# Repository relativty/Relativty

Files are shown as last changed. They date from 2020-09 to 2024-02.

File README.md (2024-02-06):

<h1 align="center">
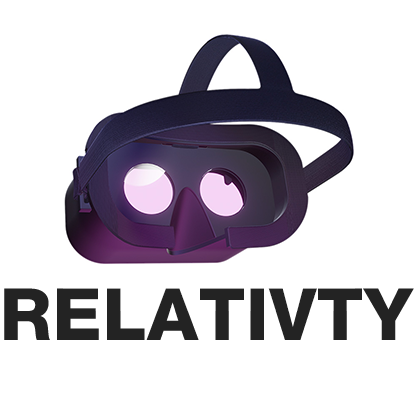
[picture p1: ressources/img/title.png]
Relativty
	
</h1>

<h3 align="center">
	Open-source VR headset with SteamVR support.
</h3>
<p align="center">
	<strong>
		<a href="https://relativty.com">Website</a>
		•
		<a href="https://discord.gg/jARCsVb">Discord</a>
	</strong>
</p>

I’m <a href="https://twitter.com/maxim_xyz?lang=en">Maxim xyz</a> and when my best friend Gabriel Combe and I were 15 years old we built our own VR headset because we couldn't afford to buy one.

5 years later : this headset became Relativty.

* Fully Open-source - **hardware**, **software**, **firmware**.
* **Steam VR** support.
* Natively displays **2K** resolution at **120FPS**.
* Compatible with **Arduino**.
* Experimental **Body-Tracking**

**This repo serves as a Build guide, to learn more about the headset see you at <a href="https://relativty.com">Relativty.com</a>**

Made for Hackers
-
Relativty is **NOT A CONSUMER PRODUCT**. We made Relativty in my bedroom with a soldering iron and a 3D printer and we expect you to do the same: **build it yourself**.

Relativty at its basics is a 3 Degrees of Freedom (3-DoF) VR headset with no built-in controller support, designed to work with SteamVR.
This may limit its practical usability for games that demand knuckle-style VR controllers.
If you are looking for a more full-featured DIY VR project 6-Dof tracking and controller support, we recommend you check out <a href="https://github.com/HadesVR/HadesVR">HadesVR</a>.

Whether or not you are building either Relativty or HadesVR, or if you just want to join our community and hang out, we invite you to <a href="https://discord.gg/F8GNKjy6RF">Relativty's Guild on Discord</a>.

It is a place for the DIY/Open-Source VR community to learn, grow, share knowledge, and ask for help. 

# Start Building Relativty

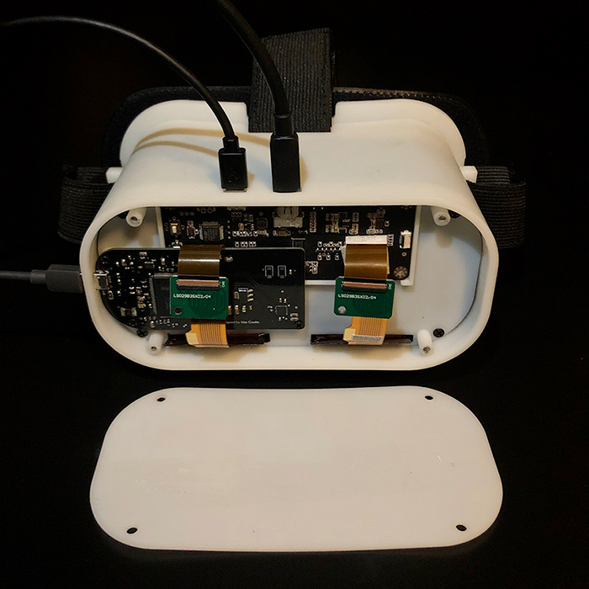
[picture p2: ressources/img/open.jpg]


# Building The Hardware
## 1. CURRENT RECOMMENDED BUILD - As of May 2023
### 1.1 Introduction
This is an updated build guide to help people who recently discovered Relativty. It aims to explain how to build the minimum functional product, which can be further improved upon and modified to the individual's liking. The original build guide can still be found further below.

            Following this guide to build a Relativty headset assumes basic understanding of electronics and programming Arduino boards.
            A VR headset is a complex system and can be difficult to figure out what is not working if you get stuck with the build.
            If you encounter any issues, join our Discord and ask for help, we are happy to assist.

### 1.2 ELECTRONICS

The following electronic components are required:

- ATmega32U4 Microcontroller (MCU) with USB HID support, such as an <a href="https://www.amazon.co.uk/diymore-Atmega32U4-Development-Microcontroller-Header/dp/B0BKGSVX2X">Arduino Pro Micro</a>
- Inertial Measurement Unit (IMU) that is supported by the <a href="https://github.com/LiquidCGS/FastIMU">FastIMU Library</a>
- A small, high resolution and high refresh rate PC display + driver board. <a href="https://github.com/HadesVR/HadesVR/blob/main/docs/Headset.md#displays">This segment of the HadesVR documentation presents possible good options you can choose from</a>. It is important to note that these displays connect to a DRIVER BOARD, which then connects to your computer. ALWAYS purchase the driver board and display(s) in the same bundle if you can to ensure they are compatible with each other. If you have further questions about displays, join us at <a href="https://discord.gg/F8GNKjy6RF">Relativty's Guild on Discord</a>.
```
NOTES on VR DISPLAYS:
- The display does not connect to the Microcontroller, it only connects to the Computer running your VR Apps.
- Technically, any PC display/monitor can be configured as the display used by Relativty. Therefore, you can simply test your build on your PC monitor
first to make sure it works, before you decide to spend a significant amount of money on lenses, display(s) and other parts.
- High performance, small form factor displays are expensive, and often very delicate. Handle them with care! :)
```

### 1.2.1 Wiring the IMU and MCU
The IMU needs to be connected to the MCU for power and communication.
The MCU connects to your computer via USB to send the IMU readings to SteamVR.

In case of an Arduino Pro Micro, you need to connect the following pins:
```
Pro Micro       IMU
VCC         ->  VCC  
GND         ->  GND  
SDA(pin 2)  ->  SDA  
SCL(pin 3)  ->  SCL  
```  
If you use a different MCU, the SDA and SCL pins might be mapped to different pin numbers.

Also, make sure that the VCC of your MCU is compatible with the rated operating voltage of your IMU.

Supplying incorrect voltage to electronic components may cause damage to them.

The MCU itself simply connects to your computer via the USB port.

### 1.2.2 Connecting the display
As mentioned previously, any display that is compatible with a personal computer should be able to function as your VR display.

In case you are using the recommended one or a similar component that is powered via micro-USB or other USB standard, it is possible that you will encounter situations where the board does not power up. This could be either because the micro-USB cable you are using is too long (so the board cannot power up because the voltage dropped too much), or the board is unable to turn on because the USB port it connects to on the computer side is simply unable to supply enough power. In this case, you might need to try different ports on your computer or a powered USB hub.

### 1.3 MECHANICAL BUILD

The following parts are required for the Mechanical Build:

- Housing - .STL files for 3D-printable model provided in Relativty_Mechanical_build folder.
- Lenses -  for building the 3D-printable headset, Lenses with 40mm diameter/50mm focal length required. You can often find these on Aliexpress or similar.
- Strap and Facial Interface - e.g. replacement strap + foam for HTC Vive. You can often find these on Aliexpress or similar.

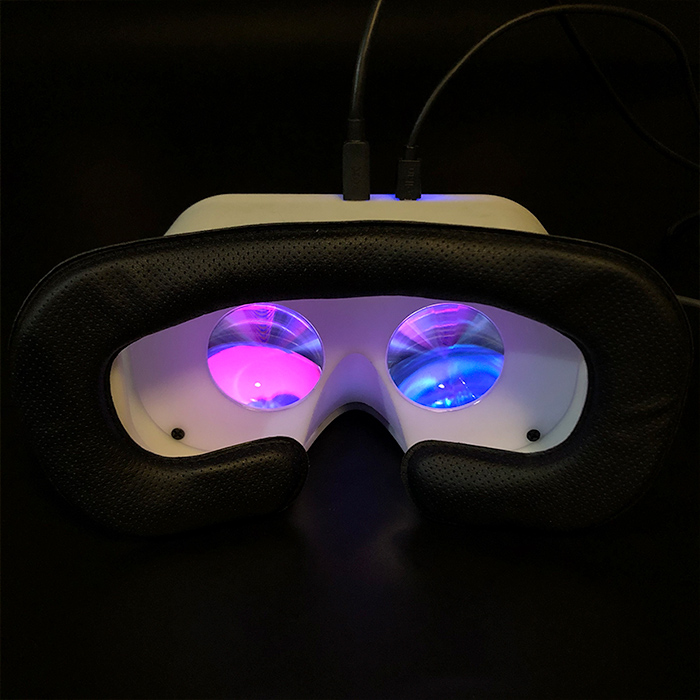
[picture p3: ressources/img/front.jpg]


If you do not have access to 3D-printing, it is also possible (and MUCH simpler) to just use an Android VR Phone case, and modify it to fit your screen and so that you can attach your IMU and MCU to it.

The advantage of this approach is that you get everything in one package, often including IPD adjustment.

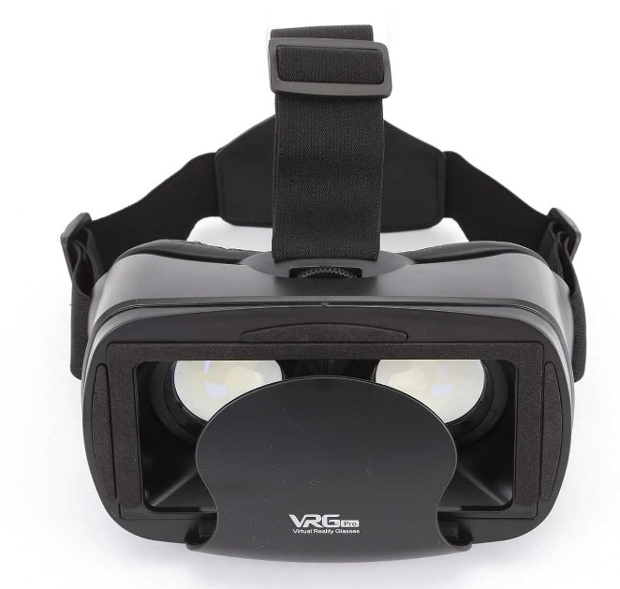
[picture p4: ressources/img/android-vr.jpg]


### 1.4 SOFTWARE SETUP

### 1.4.1 Introduction

Relativty depends on 2 main software components:
- the Arduino firmware
- the SteamVR driver

As the system is designed to work with SteamVR, you need to have Steam installed and SteamVR downloaded on your computer.

### 1.4.2 Programming your MCU

As previously mentioned, we recommend you use an Arduino Pro Micro and an IMU supported by the FastIMU Library.
FastIMU is an awesome package that supports many commonly used IMUs and comes with a pre-written Arduino sketch that works with Relativty.

First, you will need to install the Arduino IDE and connect your MCU to your computer via the USB connector.

Once you have it connected and verified your Arduino IDE can work with your MCU, download FastIMU from the library manager.

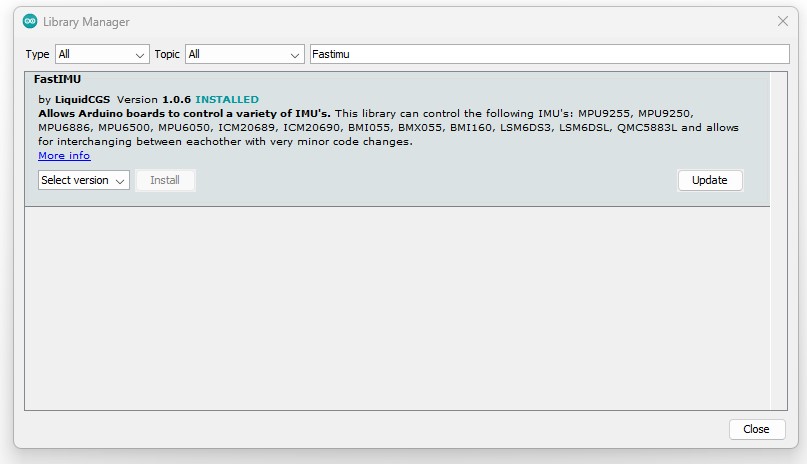
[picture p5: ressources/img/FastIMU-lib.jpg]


Wire up your IMU as recommended in Section 1.2.1.

Find the Examples/Fastimu/Calibrated_relativty sketch in your Arduino IDE:
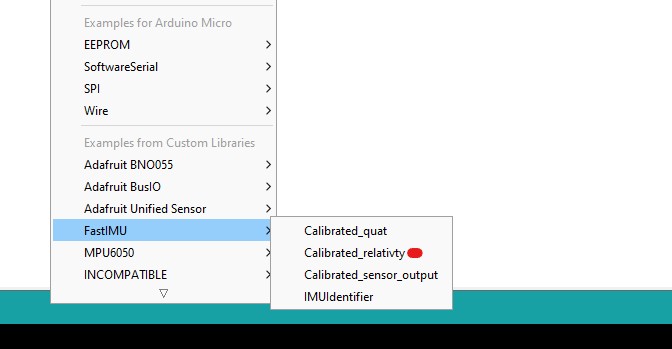
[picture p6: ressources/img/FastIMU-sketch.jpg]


And finally, Upload it to your MCU.

FastIMU also includes a built-in calibration tool that can store the calibration data on the IMUs EEPROM.

Calibrating the IMU may help with sensor drift that you can experience over time while using Relativty.

After uploading Calibrated_relativty sketch to the IMU, you can open the Arduino Serial Monitor to initiate a calibration sequence:

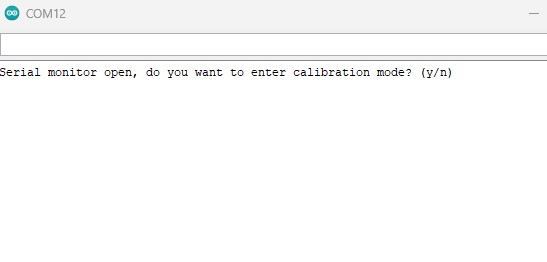
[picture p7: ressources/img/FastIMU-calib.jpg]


      NOTE: you only have to do this once, but make sure to follow the instructions given to you in the serial monitor.

### 1.4.3 Installing The SteamVR Driver

To install the Relativty SteamVR driver:
- download the <a href="https://github.com/relativty/Relativty/archive/refs/heads/master.zip">master repository</a>
- inside Relativty-master find the Relativty_Driver\Relativty folder and copy it to your SteamVR installation's drivers directory.
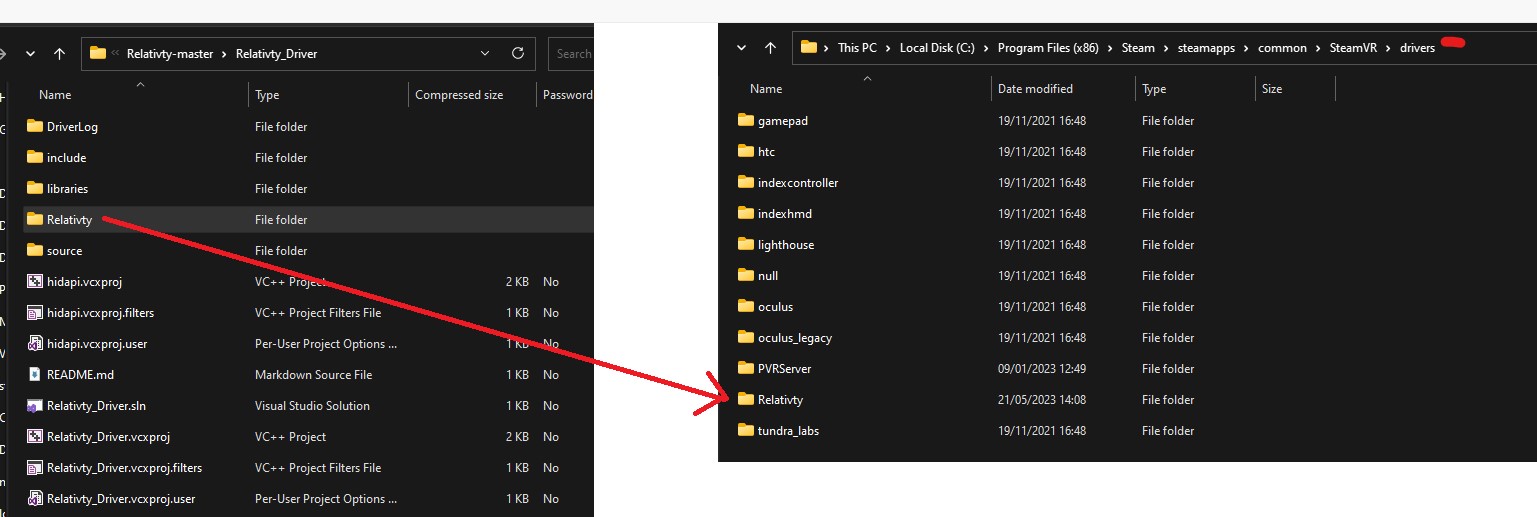
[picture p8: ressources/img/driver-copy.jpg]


### 1.4.4 Configuring The SteamVR Driver

Once you copied the driver files, it is time to configure the driver to work with your setup and computer.

Inside drivers\Relativty\resources\settings, there should be a file called default.vrsettings.

This is the configuration file for the driver.

There are a few things that you need to change.

### Configuring the driver to talk to the MCU
ASSUMING you use an Arduino Pro Micro and the FastIMU library:

In the Relativty_hmd segment find these values:
- hmdPid
- hmdVid
- hmdIMUdmpPackets

and change the values like so:

```
      "hmdPid" : 32823,
      "hmdVid": 9025,
      "hmdIMUdmpPackets":  false,
```

If you are using a different MCU, you need to figure out the USB PID and VID values.

Easiest way is to connect it to your computer via USB and check in Arduino IDE.

In the menu bar, select Tools/Get Board Info:
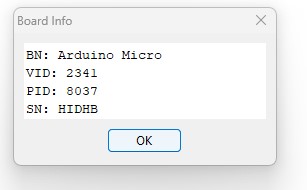
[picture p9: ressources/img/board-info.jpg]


Take the PID and VID values and convert them to decimal with a <a href="https://www.rapidtables.com/convert/number/hex-to-decimal.html">hex converter</a>.

The converted values then go into the hmdPid and hmdVid values in default.vrsettings.

### Configuring the Display Settings
Now let's look at configuring the driver to work with your Display.

The config variables for the display are in the Relativty_extendedDisplay segment:

For the VR Viewport window's point of origin:
```
      "windowX" : 3440,
      "windowY" : 0,
```

For the VR Viewport's actual size
```
      "windowWidth" : 1920,
      "windowHeight" : 1080,
```

For the VR Viewport's rendering resolution - this should be normally the same as the size
```
      "renderWidth" : 1920,
      "renderHeight" : 1080,
```

And some miscellaneous settings:
```
      "DistortionK1" : 0.4,
      "DistortionK2" : 0.5,
      "ZoomWidth" : 1,
      "ZoomHeight" : 1,
      "EyeGapOffsetPx" : 0,
      "IsDisplayRealDisplay" : true,
      "IsDisplayOnDesktop" : true
```
If the point of origin and size is not configured correctly, the driver will crash and SteamVR will not display anything!

Therefore we need to have a look at and understand the coordinate system SteamVR uses for displays.

Windows always assumes one of the connected displays as your Primary Display.

You can verify which one is your Primary in Display Settings.

You can select each of your displays with the mouse. The one that has "Make this my main display" checkbox greyed out is your Primary Display.

THIS GUIDE ASSUMES THAT THE TOP EDGE OF ALL OF YOUR DISPLAYS ARE ALIGNED IN WINDOWS DISPLAY SETTINGS (as seen on the screenshots)

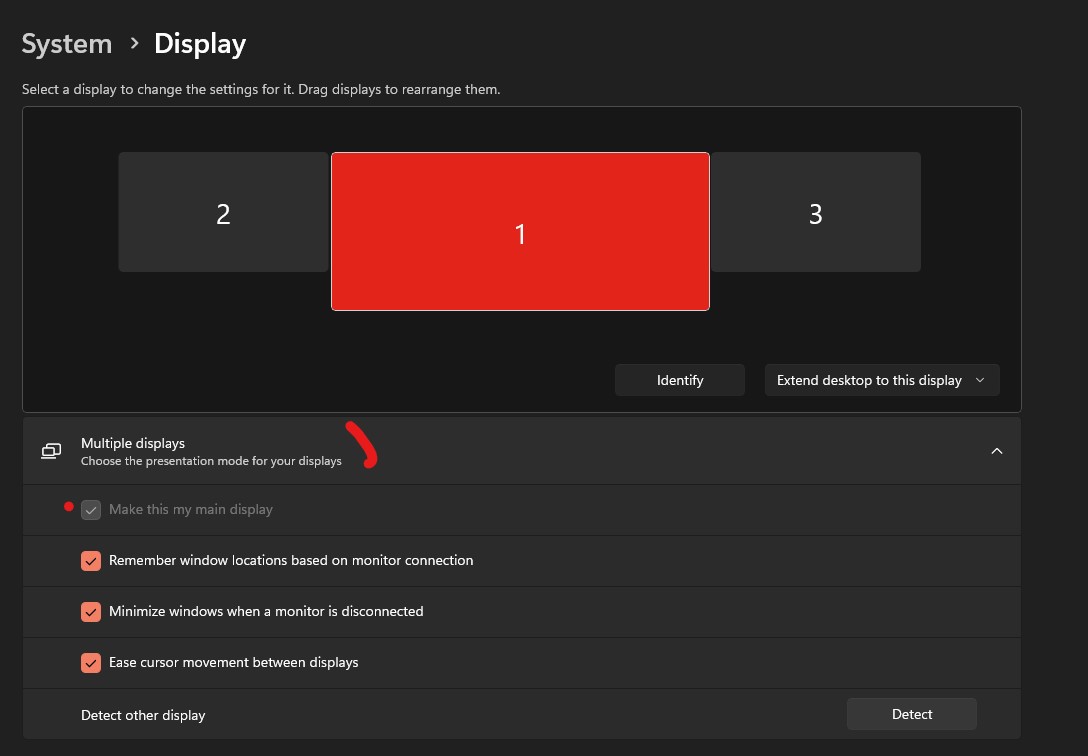
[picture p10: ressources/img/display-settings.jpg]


Consequently, checking the same on another, non-primary display will make that one your Primary.

The TOP LEFT corner of your Primary Display is the ORIGIN POINT of SteamVR's display coordinate system.

To be able to tell SteamVR where to draw the VR Viewport on your displays, you need to make sure you understand this fact and as a result can identify the correct point of origin for the Viewport.

For example, in a setup like this:

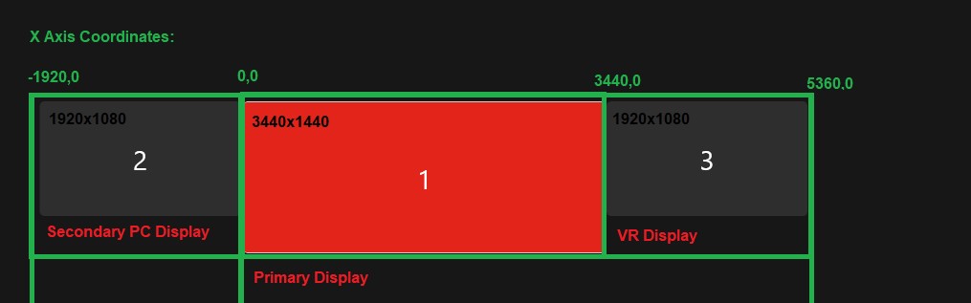
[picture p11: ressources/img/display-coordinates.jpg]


Because the "1" screen is the primary, and the "3" screen is the VR Display, the origin point (the 0,0 coordinate) is on the top left of the "1" screen.

This screen has 3440x1440 resolution.

This means it occupies the X axis from 0 to 3439, and the next screen on its right starts at point 3440.

Therefore, in this case the correct windowX and windowY values are:

```
      "windowX" : 3440,
      "windowY" : 0,
```

If "2" screen was the VR display (and "1" is still the Primary), the correct values would be:

```
      "windowX" : -1920,
      "windowY" : 0,
```
Because the "2" screen's coordinates occupy space over the other side of the origin point.

For windowWidth,windowHeight,renderWidth,renderHeight, simply set the Native Resolution of your VR display.

Once this is all set, save the settings file.

Now you should be ready to start SteamVR.

If everything is set up right, you should get straight into the vr holodeck area:

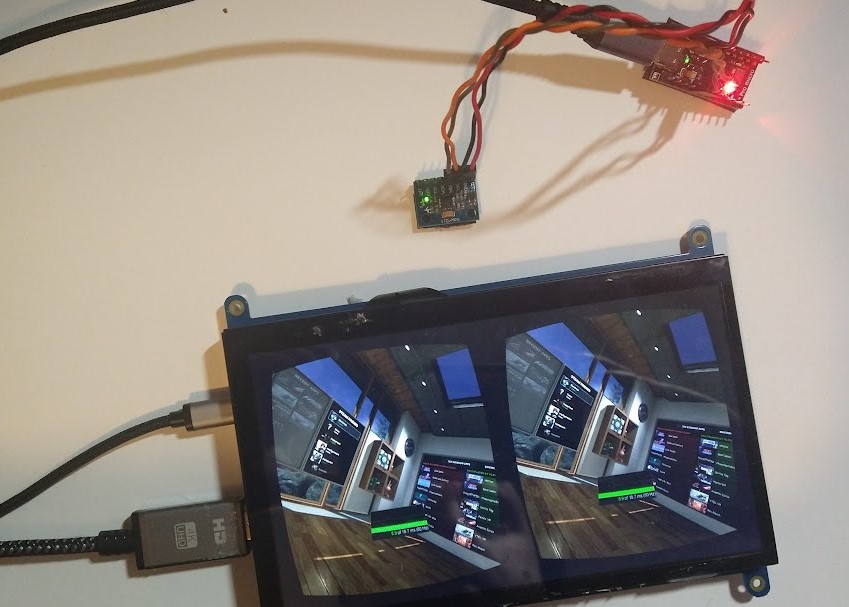
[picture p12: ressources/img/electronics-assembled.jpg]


If you are encountering any issues with your build:
- open the SteamVR Web Console and copy the entire log file
- Join <a href="https://discord.gg/F8GNKjy6RF">Relativty's Guild on Discord</a>, tell us about the issues you are facing, and upload the log file in the chat. 
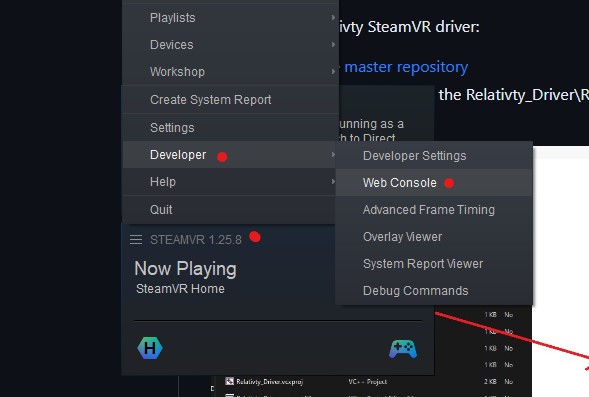
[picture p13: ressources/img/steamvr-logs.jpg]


### IF YOUR VR WINDOW DISAPPEARS AFTER CLICKING ON IT:

Open Windows PowerShell and paste these commands into the command line, then hit enter:

```
get-process vrcompositor | stop-process -Force;cd "C:\Program Files (x86)\Steam\steamapps\common\SteamVR\bin\win64";.\vrcompositor.exe
```

Afterwards the VRCompositor should remain stable, so you only have to do this once per session.

# 2. LEGACY BUILD
The hardware is based on the Relativty Motherboard which includes an Atmel SAM3X8E ARM Cortex-M3 processor and uses an MPU-6050 as it’s IMU.
Alternatively, any processor that supports the ArduinoCore and is connected to an MPU-6050/MPU-9250 can be used as the hardware for Relativty. Both methods are explained below.

## Building The Relativty Motherboard
### PCB Manufacturing.

We first start with the naked PCB.

it can be manufactured and bought for around $4 on websites like <a href="https://jlcpcb.com/">jlcpcb</a>.

You’ll need to provide the Gerber file folder `Relativty_Electronics_build/GerberFiles.zip` which describes the shape of the board.

### Assembling

Soldering the components onto the naked PCB. 

You’ll have to buy the components listed in one of the two BOMs, depending on availability:
- `Relativty_Electronics_build/Assembly/jlcpcb.com_motherboard_BOM.csv` 
- `Relativty_Electronics_build/Assembly/motherboard_BOM.xlsx`

Where to position those components on the PCB is described in the file `Relativty_Electronics_source/motherboard.brd` which can be opened in Eagle.

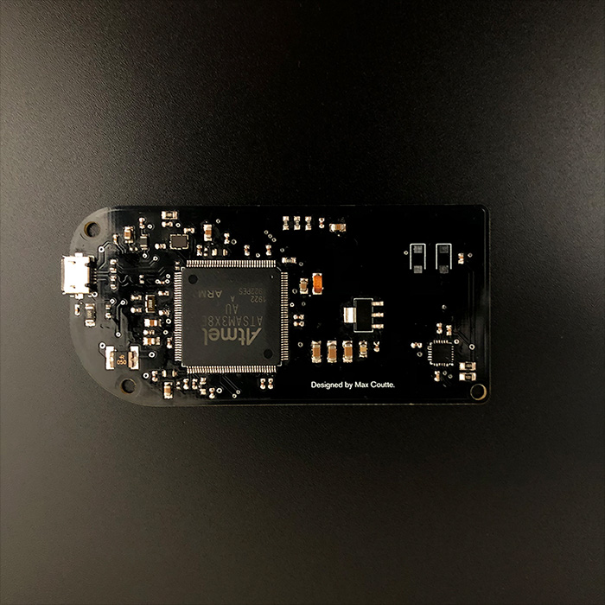
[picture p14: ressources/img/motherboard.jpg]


#### Using an Arduino

An alternative to the Relativty Motherboard is to use an Arduino Due and to connect it to an MPU-6050.
```
5V      -> VCC  
GND     -> GND  
SDA(20) -> SDA  
SCL(21) -> SCL  
PIN 2   -> INT  
```

If you are using an MPU-9250 with the alternative firmware provided the pinout is:

```
5V      -> VCC  
GND     -> GND  
SDA(20) -> SDA  
SCL(21) -> SCL   
```

Then push the `ERASE` and the `RESET` button on the Arduino Due and you’ll be able to install the Relativty Firmware.

#### Installing The Relativty Firmware

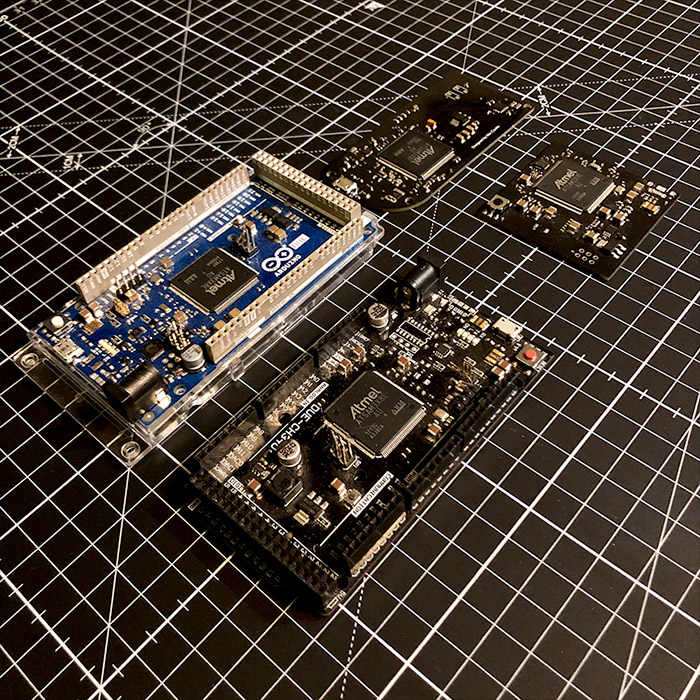
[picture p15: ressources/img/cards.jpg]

You’ll now need to install the Relativty board in the Arduino IDE. 

To do that copy that JSON URL: https://raw.githubusercontent.com/relativty/Relativty/master/Relativty_Firmware/package_Relativty_board_index.json and open the Arduino IDE

In Arduino, Click File and then Preferences:

- If you are using the Relativty PCB, aad the JSON URL to the `Additional Boards Manager` text box.
- Go to `Tools > Board > Board Manager` and you should see the Relativty Board, click install.
- Reboot the Arduino IDE and under Tools > Boards, select Relativty.
- You can now open `Relativty_Firmware/firmware/firmware.ino` and upload it to your board.

If you are using a different board e.g. Arduino Due:

- install contents of `Relativty_Firmware\Relativty_board\` to your Arduino IDE
- if you are using MPU-6050, use `Relativty_Firmware/firmware/firmware.ino`
- if you are using MPU-9250, use `Relativty_Firmware\MP9250-HID\MP9250-HID\MP9250-HID.ino`

# Building The Mechanical Parts

## Assembling the HMD

All the files needed for the 3D printing can be found in the `Relativty_Mechanical_build` folder and the screws needed to assemble the Headset are listed in `screws_BOM.xlsx`.

We've used parts from Aliexpress:

- <a href="https://www.aliexpress.com/item/33058848848.html">The Strap</a>, 
- <a href="https://www.aliexpress.com/item/4000199486058.html">The Foam</a>,
- <a href="https://www.aliexpress.com/item/33029909783.html">The Lenses</a> (40mm diameter/50mm focal length).

### The screen for the HMD
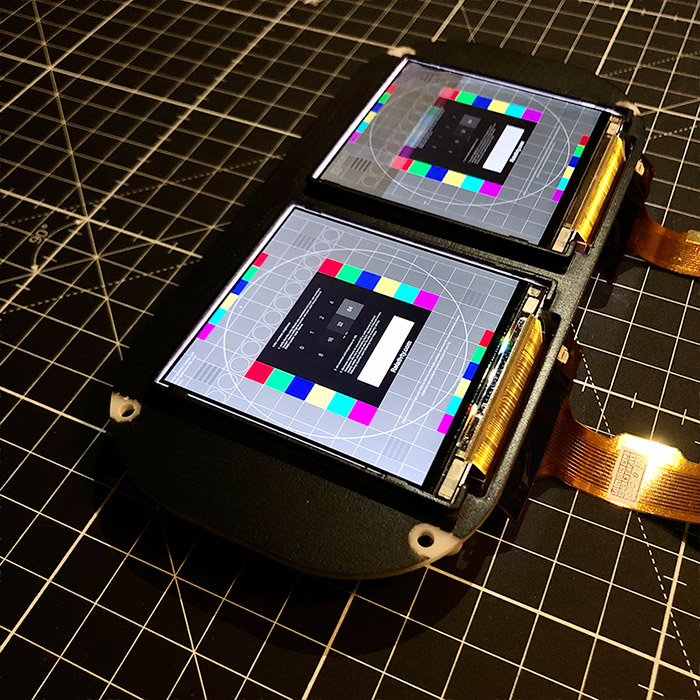
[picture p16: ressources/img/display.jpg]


Relativty Headset runs a dual-screen at 120FPS 2K, however, because of the open nature of Relativty you can equip it with any screen.

Our model can be found on Aliexpress, but depending on the vendor similar screens can cost from $150 to $190. You'll have to hunt and maybe wait for the right vendor at the right price to get the display for cheap (or buy in bulk). 

This is [the model we used](https://www.aliexpress.com/item/32975198897.html).

### Setting Up the Software



#### Installing Relativty Driver for SteamVR

The Relativty Driver is contained within `Relativty_Driver/Relativty` folder. 

⚠️ You’ll need to set it up by editing the JSON file `Relativty_Driver/Relativty/resources/settings/default.vrsettings`

If you are not using a Relativty PCB, you will need to change these:

      "hmdPid" : 9,
      "hmdVid": 4617,
	  
These are the USB HID device's unique Vendor and Producit Identifieres (pid/vid)

If you are using and Arduino Due, the correct values will be:

      "hmdPid" : 62,
      "hmdVid" : 9025,
	  
In case you are using a different board, the process to get the right values is as below:

1.	Plug your board in

2.	Select your board in Arduino IDE and click Tools/Get Board info. you will see something like this:

```
	BN: Arduino Due (Native USB Port)
	VID: 2341
	PID: 003e
	SN: HIDHB
```
3.	Make note of the VID and PID numbers. These are hexadecimal values.

	To apply them to the config, they need to be converted to int.
	
	If you are unsure how to do that, there is plenty online converters available.
	
	Such as: https://www.rapidtables.com/convert/number/hex-to-decimal.html

4.	Change your hmdPid and hmdVid values to the converted values.

Next, you need to set up the display coordinates and resolution.

At first, you should have the HMD's display set up as a secondary screen extending your desktop,

aligned onto the top right corner of your primary display.

In the config file's "Relativty_extendedDisplay" segment, find and set these:
```
      "windowX" : *whatever your primary screen resolution's width is*,
      "windowY" : 0,
      "windowWidth" : *HMD's native resolution width*,
      "windowHeight" : *HMD's native resolution height*,
      "renderWidth" : *HMD's native resolution width*,
      "renderHeight" : *HMD's native resolution height*,
	  
	  And at the bottom of this segment:
	  
      "IsDisplayRealDisplay" : true,
      "IsDisplayOnDesktop" : true
```  
	  
Make sure not to delete any "," symbols as that will break the config.

Only the last item in the config should not have a "," symbol.

If for whatever reason the above settings do not work out for you try:

Set your HMD display as a mirrored display of your primary display.

Change config as follows:
```
      "windowX" : 0,
      "windowY" : 0,
      "windowWidth" : *HMD's native resolution width*,
      "windowHeight" : *HMD's native resolution height*,
      "renderWidth" : *HMD's native resolution width*,
      "renderHeight" : *HMD's native resolution height*,
	
      "IsDisplayRealDisplay" : false,
      "IsDisplayOnDesktop" : true
	
```	
⚠️ Please note that this may result in keyboard/mouse input not being captured by the VR window, should your game require it, it might become unplayable.

You can also make IPD (Interpupillary Disance) adjustments within the configuration file:

In the "Relativty_hmd" segment find and adjust:

```
      "IPDmeters" : 0.063,
```

You can also change the lens distortion correction by changing these:

```
      "DistortionK1" : 0.4,
      "DistortionK2" : 0.5,
```

You can now install Relativty Driver:
- Locate your `vrpathreg.exe` program, usually located at `C:/Steam/steamapps/common/SteamVR/bin/win64/vrpathreg.exe`
- Then open the Windows Command Prompt and run the following commands:
`cd C:/Steam/steamapps/common/SteamVR/bin/win64
vrpathreg.exe`

And then assuming your `Relativty_Driver/Relativty` driver folder is located at:
`C:/code/Relativty_Driver/Relativty`
- run `vrpathreg adddriver C:/code/Relativty_Driver/Relativty`

Relativty Driver is now installed. You can uninstall it any time by running:  
- `vrpathreg removedriver C:/code/Relativty_Driver/Relativty`

#### Setting up the Experimental 3D Tracking

The tracking is still very experimental and can only be run on NVIDIA GPU due to the usage of CUDA. The tracking makes uses of only a video input and an Artificial Neural Network AI trained to estimate a 3D body position. 

This method is nothing close to the precision or freedom of movements of a dedicated sensor however we believe that the model can be trained and improved by orders of magnitude.

You first need to connect a webcam to your computer and install Python 3.8.4 and select the option to add it to the path. Then install `PyTorch`, you can do so by running the following commands:

`python -m pip install torch===1.6.0 torchvision===0.7.0 -f https://download.pytorch.org/whl/torch_stable.html`

Then proceed to install `CUDA Toolkit 11.0.`

You’ll then need to download the Folder `PYTHONPATH` at https://github.com/relativty/Relativty/releases and add its location to `PyPath` in the `JSON Relativty_Driver/Relativty/resources/settings/default.vrsettings`

Set `tracking` to 1. The tracking is now turned on and can be turned off anytime by setting `tracking` to 0. The tracking can also be calibrated depending on your camera, this can be done by tweeking `scalesCoordinateMeter` and `offsetCoordinate`. `scalesCoordinateMeter` correspond to the delta of coordinates in a given axis calculated by the AI after normalization when you move 1 meter in that given axis.

**Note:** If you plan on using mpu9250 firmware do not forget to switch to it in the driver by setting `hmdIMUdmpPackets` to `false`:
`"hmdIMUdmpPackets":  false,`

## Final Steps

Everything is now set up to start playing. 

To start using Relativty:
- Lay the headset on a flat surface with the front panel facing the ground
- Plug in the Headset.
It’ll automatically calibrate after a few seconds.

You can now run any SteamVR game!

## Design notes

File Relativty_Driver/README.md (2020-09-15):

# *the driver*

to compile thy code one mustn't use `Debug`, thou shall use `Release` to compile thy scriptures

thou will summon the compiler god's wrath, shall thou one use `Debug`

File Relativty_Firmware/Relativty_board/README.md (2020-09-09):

# Arduino Core for SAM3X CPU

This repository contains the source code and configuration files of the Arduino Core for Atmel's SAM3X processor (used on the [Arduino Due](https://www.arduino.cc/en/Main/ArduinoBoardDue) board).

## Installation on Arduino IDE

This core is available as a package in the Arduino IDE cores manager.
Just open the "Boards Manager" and install the package called:

 * **Arduino SAM Boards (32-bit ARM Cortex-M3)**

## Support

There is a dedicated section of the Arduino Forum for general discussion and project assistance:

http://forum.arduino.cc/index.php?board=87.0

## Bugs or Issues

If you find a bug you can submit an issue here on github:

https://github.com/arduino/ArduinoCore-sam/issues

Before posting a new issue, please check if the same problem has been already reported by someone else to avoid duplicates.

## Contributions

Contributions are always welcome.
The preferred way to receive code contribution is by submitting a Pull Request on github.

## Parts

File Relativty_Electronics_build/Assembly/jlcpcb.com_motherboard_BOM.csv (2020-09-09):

Comment | Designator | Footprint | LCSC Part #（optional）
USB_MICRO-B_FEMALE-SMT | J1 | USB-B-MICRO-SMD
0.1uF | C40, C42 | 0402 | C1525
0.47uF | C1 | 0805 | C13967
100KOhm | R4, R5, R6, R7 | 0603 | C25803
100nF | C18 | 0402 | C1525
100nF | C6, C11, C12, C14, C15, C16, C20, C21, C22, C24, C25, C26, C27, C28, C29, C30, C36, C38, C39 | 0402 | C1525
10nF | C7, C37, C44 | 0402 | C15195
10uH | L1, L2, L4 | 0805C | C1046
12MHz | Y2 | CRYSTAL-SMD-3.2X2.5MM | C93234
1MOhm | R13 | 1206 | C17927
1Ohm | R1, R2, R3 | 0402 | C25125
2.2nF | C41 | 0402 | C1531
22pF | C8, C31, C32, C33, C34 | 0402 | C1555
22uF | C2, C3, C4 | 1206 | C5672
32.768 kHz | Y1 | CRYSTAL-SMD-3.2X1.5MM | C32346
33uF | C5 | 1206 | C128347
39Ohm | R8, R9 | 0402 | C25110
4.7KOhm | R11, R12 | 0805 | C17673
4.7nF | C43 | 0402 | C1538
4.7uF | C9, C10, C13, C17, C19, C23, C35 | 0805 | C1779
6.8KOhm | R10 | 0805 | C17772
ATSAM3X8EA-AU | U1 | LQFP144 | C79305
CG0603MLC-05E | RV1, RV2, RV3 | 0603 | C20959
LM3940IMPX-3.3/NOPB | U2 | SOT-223-4 | C140319
MF-SMDF050 | F1 | MF-SMDF050 | C12558
Beads | L3 | 0805 | C1015
MPU-6050 | U3 | 24-QFN (4x4) | C24112
SKRKAEE020 | ERASE, RESET | SOD4829X200

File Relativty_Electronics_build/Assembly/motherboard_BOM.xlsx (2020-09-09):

Item # | Ref Des | Qty | Manufacturer | Mfr. Part # | Value, Description | Package | Type | Link
1 | J1 | 1 | Molex | 473460001 | USB_MICRO-B_FEMALE-SMT | USB-B-MICRO-SMD | SMD | https://www.digikey.fr/product-detail/en/molex/0473460001/WM17141CT-ND/1782474
2 | C40, C42 | 2 | Yageo | CC0402KRX7R6BB104 | 0.1µF ±10% 10V Ceramic Capacitor X7R 0402 | 0402 | SMD | https://www.digikey.com/product-detail/en/yageo/CC0402KRX7R6BB104/311-1345-1-ND/2103129
3 | C1 | 1 | KEMET | C0805C474K3PAC7800 | 0.47µF ±10% 25V Ceramic Capacitor X5R 0805 | 0805 | SMD | https://www.digikey.com/product-detail/en/kemet/C0805C474K3PAC7800/399-15508-1-ND/7386906
4 | R4, R5, R6, R7 | 4 | Yageo | RC0603FR-07100KL | 100 kOhms ±1% 0.1W, 1/10W Chip Resistor 0603 | 0603 | SMD | https://www.digikey.com/product-detail/en/yageo/RC0603FR-07100KL/311-100KHRCT-ND/729836
5 | C18 | 1 | Murata Electronics | GRM033C71C104KE14D | 100nF 10% 16V Ceramic Capacitor X7S 0201 | 0201 | SMD | https://www.digikey.com/product-detail/en/murata-electronics/GRM033C71C104KE14D/490-10387-1-ND/5026260
6 | C6, C11, C12, C14, C15, C16, C20, C21, C22, C24, C25, C26, C27, C28, C29, C30, C36, C38, C39 | 19 | Yageo | CC0402KRX7R6BB104 | 100nF ±10% 10V Ceramic Capacitor X7R 0402 | 0402 | SMD | https://www.digikey.com/product-detail/en/yageo/CC0402KRX7R6BB104/311-1345-1-ND/2103129
7 | C7, C37, C44 | 3 | Yageo | CC0402KRX7R7BB103 | 10nF ±10% 16V Ceramic Capacitor X7R 0402 | 0402 | SMD | https://www.digikey.com/product-detail/en/yageo/CC0402KRX7R7BB103/311-1042-1-ND/302959
8 | L1, L2, L4 | 3 | TDK Corporation | MLZ2012N100LT000 | 10uH | 0805C | SMD | https://www.digikey.com/product-detail/en/tdk-corporation/MLZ2012N100LT000/445-6762-1-ND/2523583
9 | Y2 | 1 | Yangxing Tech | X322512MSB4SI | 12MHz ±10ppm 20pF 80Ω SMD-3225_4P SMD Crystal Resonators RoHS | CRYSTAL-SMD-3.2X2.5MM | SMD | https://lcsc.com/product-detail/SMD-Crystal-Resonators_Yangxing-Tech-X322512MSB4SI_C9002.html
10 | R13 | 1 | Yageo | RC1206JR-071ML | 1 MOhms ±5% 0.25W, 1/4W Chip Resistor 1206 (3216 Metric) Moisture Resistant Thick Film | 1206 | SMD | https://www.digikey.com/product-detail/en/yageo/RC1206JR-071ML/311-1.0MERCT-ND/732134
11 | R1, R2, R3 | 3 | Yageo | RC0402FR-071RL | 1 Ohms ±1% 0.063W, 1/16W Chip Resistor 0402 (1005 Metric) Moisture Resistant Thick Film | 0402 | SMD | https://www.digikey.com/product-detail/en/yageo/RC0402FR-071RL/311-1.00LRCT-ND/729461
12 | C41 | 1 | Yageo | CC0402KRX7R7BB222 | 2.2nF ±10% 16V Ceramic Capacitor X7R 0402 | 0402 | SMD | https://www.digikey.com/product-detail/en/yageo/CC0402KRX7R7BB222/311-1707-1-ND/5195609
13 | C8, C31, C32, C33, C34 | 5 | Yageo | CC0402JRNPO7BN220 | 22pF ±5% 16V Ceramic Capacitor C0G, NP0 0402 | 0402 | SMD | https://www.digikey.com/product-detail/en/yageo/CC0402JRNPO7BN220/311-3744-1-ND/8024833
14 | C2, C3, C4 | 3 | KEMET | C1206C226M9PACTU | 22µF ±20% 6.3V Ceramic Capacitor X5R 1206 | 1206 | SMD | https://www.digikey.com/product-detail/en/kemet/C1206C226M9PACTU/399-8183-1-ND/3471906
15 | Y1 | 1 | Seiko Epson | Q13FC1350000400 | 32.768KHz ±20ppm 12.5pF 70kΩ SMD-3215_2P SMD Crystal Resonators RoHS | CRYSTAL-SMD-3.2X1.5MM | SMD | https://lcsc.com/product-detail/SMD-Crystal-Resonators_Seiko-Epson_Q13FC1350000400_Seiko-Epson-Q13FC1350000400_C32346.html
16 | C5 | 1 | TDK Corporation | C3216X5R1A336M160AB | 33µF ±20% 10V Ceramic Capacitor X5R 1206 (3216 Metric) | 1206 | SMD | https://www.digikey.com/product-detail/en/tdk-corporation/C3216X5R1A336M160AB/445-6005-1-ND/2444046
17 | R8, R9 | 2 | Yageo | RC0402FR-0739RL | 39 Ohms ±1% 0.063W, 1/16W Chip Resistor 0402 | 0402 | SMD | https://www.digikey.com/product-detail/en/yageo/RC0402FR-0739RL/311-39.0LRCT-ND/729549
18 | R11, R12 | 2 | Yageo | RC0805JR-074K7L | 4.7 kOhms ±5% 0.125W, 1/8W Chip Resistor 0805 | 0805 | SMD | https://www.digikey.com/product-detail/en/yageo/RC0805JR-074K7L/311-4.7KARCT-ND/731274
19 | C43 | 1 | Yageo | CC0402KRX7R7BB472 | 4700pF ±10% 16V Ceramic Capacitor X7R 0402 (1005 Metric) | 0402 | SMD | https://www.digikey.com/product-detail/en/yageo/CC0402KRX7R7BB472/311-1709-1-ND/5195611
20 | C9, C10, C13, C17, C19, C23, C35 | 7 | Yageo | CC0805KRX5R5BB475 | 4.7µF ±10% 6.3V Ceramic Capacitor X5R 0805 | 0805 | SMD | https://www.digikey.com/product-detail/en/yageo/CC0805KRX5R5BB475/311-3422-1-ND/7164443
21 | R10 | 1 | Yageo | RT0805BRD076K8L | 6.8 kOhms ±0.1% 0.125W, 1/8W Chip Resistor 0805 (2012 Metric) Thin Film | 0805 | SMD | https://www.digikey.com/product-detail/en/yageo/RT0805BRD076K8L/YAG1966CT-ND/5139414
22 | U1 | 1 | Microchip Technology | ATSAM3X8EA-AU | ATSAM3X8EA-AU, AT91SAM ARM-based Flash MCU ATSAM3X8EA-AU | LQFP144 | SMD | https://www.digikey.fr/product-detail/en/microchip-technology/ATSAM3X8EA-AU/ATSAM3X8EA-AU-ND/3128687
23 | RV1, RV2, RV3 | 3 | Bourns Inc. | CG0603MLC-05E | CG0603MLC-05E, Varistor, ESD Protector, 5VDC,20V,0603 Bourns MLC Series Power Varistor 0.5pF 20V 0603 Case | 0603 | SMD | https://www.digikey.fr/product-detail/en/bourns-inc/CG0603MLC-05E/CG0603MLC-05ECT-ND/3438061
24 | U2 | 1 | Texas Instruments | LM3940IMPX-3.3/NOPB | LM3940IMPX-3.3/NOPB, Low Dropout Regulator | SOT-223-4 | SMD | https://www.digikey.com/product-detail/en/texas-instruments/LM3940IMPX-3.3-NOPB/LM3940IMPX-3.3-NOPBCT-ND/3526977
25 | F1 | 1 | Bourns Inc. | MF-SMDF050-2 | MF-SMDF050, MF-SMDF Series - PRC Resettable Fuses | MF-SMDF050 | SMD | https://www.digikey.com/product-detail/en/bourns-inc/MF-SMDF050-2/MF-SMDF050-2CT-ND/662854
26 | L3 | 1 | Würth Elektronik | 74279206 | FERRITE BEAD 30 OHM 0805 1LN | 0805 | SMD | https://www.digikey.com/product-detail/en/w-rth-elektronik/74279206/732-1611-1-ND/1639555
27 | U3 | 1 | TDK InvenSense | MPU-6050 | MPU-6050, Invensense MPU-6050 6-Axis Gryoscope/Accelerometer | 24-QFN (4x4) | SMD | https://www.digikey.com/product-detail/en/tdk-invensense/MPU-6050/1428-1007-1-ND/4038010
28 | ERASE, RESET | 2 | ALPS Electric | SKRKAEE020 | SKRKAEE020 | SOD4829X200 | SMD

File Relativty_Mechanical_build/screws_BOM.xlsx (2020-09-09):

Thread # | Qty | Thickness | Length | Description | Manufacturer | Link
1 | 4 | M1.6 | 3 | Phillips | YINSONG | https://www.amazon.fr/YINSONG-M1-6-M1-7-Vis-M%C3%A9taux/dp/B07PVNMQYZ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
2 | 4 | M3 | 4 | Phillips | XFentech | https://www.amazon.fr/XFentech-Vis-m%C3%A9taux-Cruciforme-%C3%A9lectroniques/dp/B07PRWBBSZ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
3 | 4 | M3 | 6 | Phillips | YINSONG | https://www.amazon.fr/YINSONG-Vis-M%C3%A9caniques-M3-%C3%A9lectroniques/dp/B07PVNLTH3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
4 | 4 | M3 | 6 | Phillips | YINSONG | https://www.amazon.fr/YINSONG-Vis-M%C3%A9caniques-M3-%C3%A9lectroniques/dp/B07PVNLTH3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
5 | 4 | M4 | 8.5 | Thumb Screw | sourcingmap | https://www.amazon.fr/Sourcingmap%C2%AE-plaqu%C3%A9-Renforcent-molet%C3%A9-Boulons/dp/B01HSTUO1K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
6 | 4 | M3 | 4 | Phillips | XFentech | https://www.amazon.fr/XFentech-Vis-m%C3%A9taux-Cruciforme-%C3%A9lectroniques/dp/B07PRWBBSZ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

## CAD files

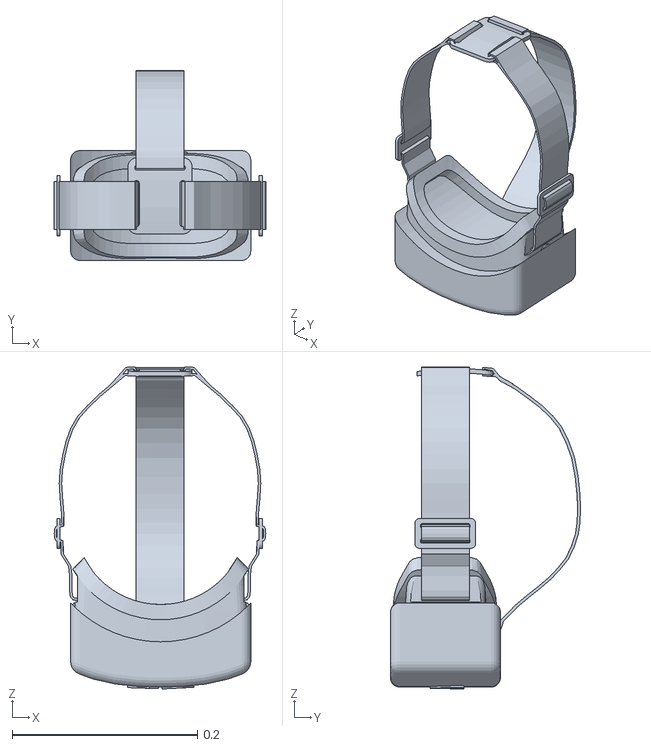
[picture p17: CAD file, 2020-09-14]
Relativty_Driver/Relativty/resources/rendermodels/generic_hmd/generic_hmd.obj
0.228 x 0.205 x 0.348

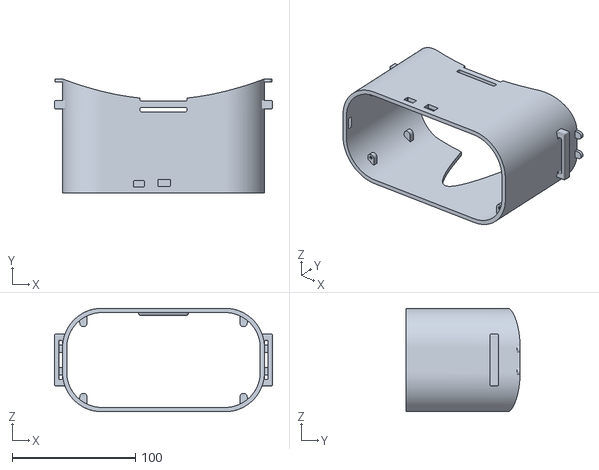
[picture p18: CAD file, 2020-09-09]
Relativty_Mechanical_build/body.stl
177.0 x 92.7 x 84.0

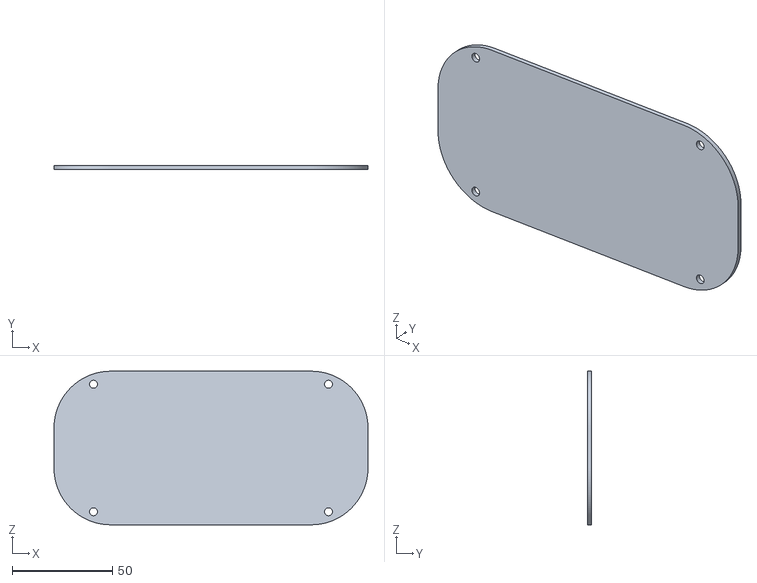
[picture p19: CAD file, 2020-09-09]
Relativty_Mechanical_build/front_panel.stl
156.6 x 2.00 x 76.6

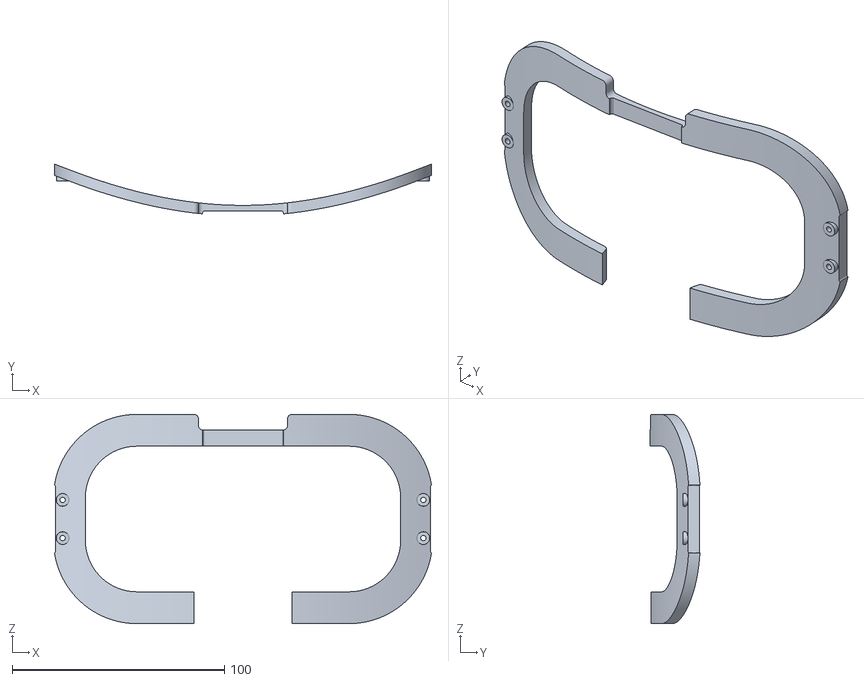
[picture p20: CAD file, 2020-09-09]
Relativty_Mechanical_build/foam_support.stl
177.7 x 23.5 x 98.6

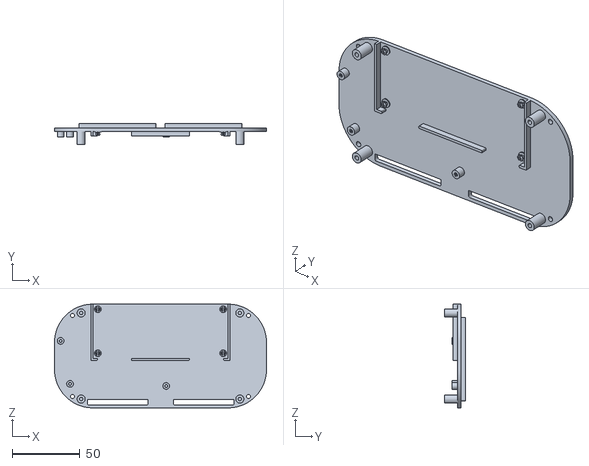
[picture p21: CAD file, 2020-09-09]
Relativty_Mechanical_build/screen_panel.stl
156.6 x 15.5 x 76.6

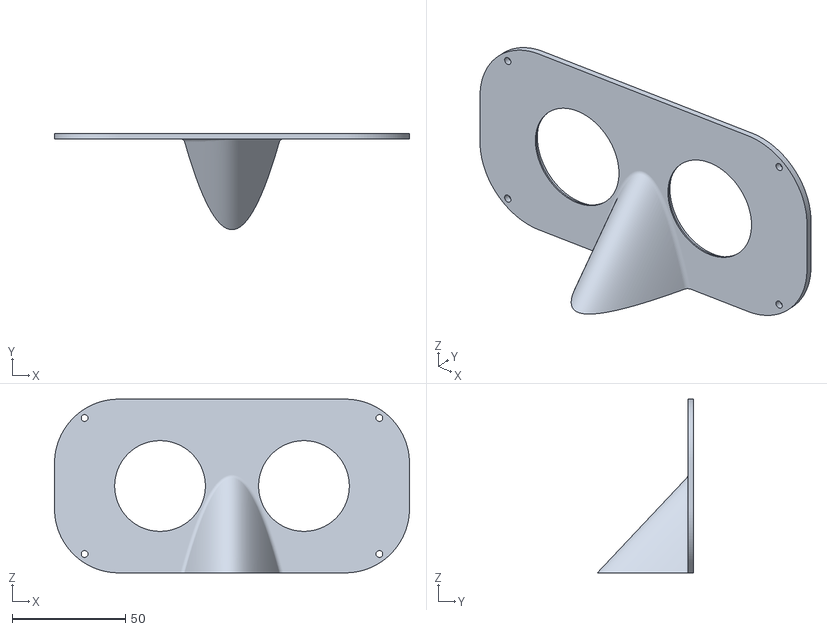
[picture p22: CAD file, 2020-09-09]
Relativty_Mechanical_build/eyes_panel.stl
156.6 x 42.5 x 76.6

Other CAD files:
Relativty_Mechanical_source/mechanic.f3d

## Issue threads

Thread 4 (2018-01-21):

Massively Extending game/software support

LifeIsStrange, 2018-01-21:
Well, first of all thank you for this open source project, you seems to be a funny team and I hope this will become famous :)

But it would be really Nice to add support for openXR (the next crossplatform, crosshardware native standard)
https://www.khronos.org/openxr

For https://webvr.info/

And optionally for the current attempt of standard (that will be succeeded by openXR)
http://www.osvr.org/

maxime-coutte, 2018-01-21:
Thanks for the links! I will take a look and work on it !

LifeIsStrange, 2018-01-21:
Good luck ! That will not be easy but the advantages of those specs is that with those standards you benefits from the gpu drivers optimisations that were oculus only before !

As for webVR, you may look at the servo opensource implementation, and probably ask a few questions to the dev mortimergoro :
https://blog.mozvr.com/webvr-servo-architecture-and-latency-optimizations/

But if you don't reimplement yourself the webVR I believe you should port a browser to your headset.
I really see now the need to have an opensource VR OS.. Maybe there already exist VR Linux distributions ? That would save all those issues because Linux already support webVR and OSVR, and will support openXR.
If such a distribution doesn't yet exist that could be your project, and that would be really badass.

Anyway the scope of those goals being big, I heavily suggest you to do a crowdfunding like had done oculus to be known.

maxime-coutte, 2018-01-21:
A crowdfunding without selling anything right ?

maxime-coutte, 2018-01-21:
If you want to get involved, I just created this channel for Relativty: https://discordapp.com/invite/W9VKbjU

rpavlik, 2018-01-21:
OSVR support is a great idea (I'm the maintainer, so biased, but...).  Haven't looked too much at your device yet so I don't know the details of the hardware, but we designed the plugin system to be very easy to connect to whatever hardware or existing sdk you may or may not have. And, one way or another we're planning to keep all existing device support - OSVR started as the most widely compatible framework and it will stay that way - even once OpenXR is public (and I'm on the committee) so don't worry about that part.

(Oh and btw, a ~$250 headset that supports, e.g. OSVR and steamvr does not, in fact, sell like hotcakes, even before Oculus and Vive price cuts happened, from experience, and is probably not a great source of profit en-masse, just as a caution, but don't let me dampen your enthusiasm for VR or your do-it-yourself spirit :D )

rpavlik, 2018-01-21:
FYI, there's some simple sensor fusion code included in OSVR/VRPN that should be reasonable usable on an MPU6050 (at least, if you have it configured approximately like the Oculus dk/dk2 -they opened those designs after several years so I've seen lots of clones of them and it works pretty well), as well as some modular camera-based positional tracking code as well as the associated firmware if you want something nearly off the shelf, otherwise you're also welcome to use the Kalman filter framework and code that is bundled with OSVR as well. It's very much doable for students to hack on: I came from academia so it's based on both the best work I've seen and the best papers I've read, and I've included citations to the papers in the code.

While OSVR and the commercial clients of Sensics is my day job, and those clients have me pretty busy, I'll try to offer at least a pointer if you get stuck and post a question in issues or something. (Just don't use Reddit, I don't use it anymore because the community was somewhat hostile)

(BTW, you can get the tracking camera from the hdk sold separately at osvrstore.com - it has some firmware issues in that it blends frames together a bit, which made our algorithm which used synchronized blinking a bit of a struggle, but it's still a good IR camera sensor that does 100fps, )

Closed 2018-01-21.

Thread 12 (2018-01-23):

Some questions

Akito13, 2018-01-23:
I was talking extensively with my friend about this project, because we find it very interesting. When we checked out the components needed for the system, we figured that the Arduino Due would be quite an overkill for its job here. Did you choose this specific device on purpose or did you just pick an Arduino Due because it was more convenient in your situation?
According to our results a way weaker micro controller could be used in this scenario.

Secondly, how important is it that the screen has at least 1440p? Did you test it with a lower resolution to see if it is garbage or acceptable?

maxime-coutte, 2018-01-23:
Lower resolutions are acceptable 🙂 We use Arduino Due for the Native USB.

I would love to talk more about the project with you. Maybe we can chat on the discord Fellowship or you can ping me ? maxime@relativty.com

Akito13, 2018-01-23:
I sent you an e-mail.

eracoon, 2018-01-23:
An Arduino pro micro would do the trick also I believe then since it's an
HID device with native USB. No?

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

Closed 2018-01-23.

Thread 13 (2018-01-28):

[Improvement] Switch from MPU-6050 6 axis sensor to MPU-9250 9 axis

luckcolors, 2018-01-28:
As previously discussed on discord, using a gyroscope without a fixed reference point causes yaw drift to happen to on the Z axis on long sessions (this naturally happens due to earth's rotation).
Switching to the MPU-9250 a 9 axis sensor gives us access to the (magnetometer) compass wich allows us to get the referece point on earth's north.
Doing this change will make the expense fom the sensor from 0.80-1$ to 2$, (in my opinion something that is worth the extra 1$ :) ) .
We could also use alternative sensors like the BNO055 but it's 10$ on aliexepress.

eracoon, 2018-01-28:
that's a very interesting point.
but won't any stronger magnetic field throw off the sensor a bit?

On Mon, Jan 29, 2018 at 12:09 AM, luckcolors <notifications@github.com>
wrote:

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

--
Jim van Hazendonk
www.racoon.media

maxime-coutte, 2018-01-29:
We should do this.
I will order an MPU-9250 today.

luckcolors, 2018-02-05:
Umm, soo what's the decision on this? If you decided that we should switch, we should update the Readme as well and make the necessary code changes.

maxime-coutte, 2018-02-05:
@luckcolors I haven’t received my MPU9250 yet. You can make the necessary code changes, PR,  and I will update the code when tested.

delp, 2018-02-08:
I ordered an MPU9250 as well and will perform testing with it in my build when it arrives.

luckcolors, 2018-02-08:
Awesome! When you get the sonsor in your hands we should start to discuss about the code required to make the sensor and the error correction work.

kasokz, 2018-02-13:
Instead of proposing the MPU-9250 which contains a MPU-6500 as improvement, couldn't we use the MPU-9150? MPU-9150 contains the MPU-6050, which we are already familiar with, and an additional magnetometer.
The magnetometer of the MPU-9250 is a little better than the one inside the MPU-9150, but that shouldn't make much of a difference.
Source of the statement here: http://www.sureshjoshi.com/embedded/invensense-imus-what-to-know/

luckcolors, 2018-02-15:
I think if we can get a newer sensor the better, if you notice at the end of the MPU-9150 page's there's a note saying it's discontinued.

Ybalrid, 2018-02-17:
The Oculus DK1 used a magnetometer to correct yaw drift (and the included accelerometer to have a vertical reference too). But it really used to be a pain to calibrate correctly...

I think the direction you should go toward, it you want to make this project evolve, would be to add an external optical tracking system, and add positional tracking too.

You would kill two birds in one stone as you would have two sources for the user's head orientation, one being absolute, and not integrated over time...

It could be as simple as a few LEDs on the headset and a cheap webcam watching the user. But it would require more processing on the computer side. If implemented, the hardware cost would still be quite low, and it could be just an "additional" upgrade to the base system.

Just some random thoughts ^^"

ToastTea, 2018-02-17:
Here are a couple open-source projects for head tracking so you don’t have to reinvent the wheel.  http://www.free-track.net/english/
And
http://www.edtracker.org.uk/

delp, 2018-02-17:
@Ybalrid I've been playing around with trying to get positional information from a xbox 360 Kinect. I have it working physically and though it's nice hardware for a good price (Usually about $10 at the thrift store) I have had a really difficult time with all of the software made for it (at least on linux.) None of it has aged very well. I spent several weeks battling horrible dependency problems and never succeeding in getting anything beyond LibFreeNect to work. So I think I've ruled out the Kinect as a road I want to go down, personally.

But I think I agree with you, in my mind the ideal solution for positional tracking would be a simple cheap IR/Camera setup that also sends info to the computer. I would like to try this at some point once the main headset has some more builds and testing.

At this point we are really just in need of as many people as possible to try 1) sourcing affordable parts 2) assembling from the info we have 3) documenting the good and bad and any build/software problems.

xmak, 2018-06-24:
Is there any progress with integrating MPU-9250 or MPU-9150?

AdmiraalHugo, 2019-04-17:
With the change to the STM32 board, a upgrade to the MPU-9250 is planned. We hope to implement this future in a few months.

JustinS-B, 2019-05-31:
We now have headset-ready code available to test out the MPU-9250 and MPU-9255 based boards.

bentalebahmed, 2019-07-12:
you should try Microsoft Kinect , i have tried it for positional tracking and then sending data to android phone that supports VR also added a haptic feedback system, you can check this link (research poster submitted for VRST 2018 in Tokyo ):
https://hal.archives-ouvertes.fr/hal-02052104/document

Closed 2019-05-31.

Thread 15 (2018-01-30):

Replace Arduino Due with ESP32

fharni, 2018-01-30:
Why you don't replace the Arduino Due with an ESP32. It is much faster and has a lot more flash memory. In china you can get a [developer board](https://de.aliexpress.com/item/ESP-32-ESP-32S-Entwicklungsboard-WiFi-Bluetooth-Ultra-niedrigem-Stromverbrauch-Dual-Cores-ESP32-Bord/32844181786.html) for about 5 €.
Here is a [comparision chart of some boards](https://hilo90mhz.com/arduino-esp32-esp8266-101-speed-test-comparison-chart/)

maxime-coutte, 2018-01-30:
Thanks I will take a look at it 😊

fharni, 2018-01-30:
Next advantage is onboard WiFi an Bluetooth.

maxime-coutte, 2018-01-30:
First we will release the SteamVR compatibility with the current Hardware and then maybe switch to ESP32 + MPU9250 😊

maxime-coutte, 2018-01-30:
Thanks a lot for the suggestion, it will help a lot.

Krossom, 2018-02-01:
but how is the development with ESP32? language... etc

fharni, 2018-02-01:
You can program it in the same way like the Arduino. Here is an instruction how to [get started](https://github.com/espressif/arduino-esp32) with the Arduino IDE and the ESP32.

maxime-coutte, 2018-02-05:
@fharni If you want to start working on a ESP version of the headset you should join our Fellowship, some peoples are also working on this. We would love to make the headset compatible with ESP !

Closed 2018-02-05.

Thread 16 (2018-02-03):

Update Headset Form

Lootgeier, 2018-02-03:
The Form of the Headset doesnt look comfortable at all.
Is there a possibility to update it so it sits firmly and is not so boxy?
Maybe compatible with the Foampad from the Samsung Galaxy VR (7€) foam piece.
And where to get the headstraps and stuff?
Maybe it would be possible to merge this project with "WiFiBroadcast" from Raspberry so it gets fully Wireless with a powerbank. Im really looking to the improvements but im not good at 3D modelling but im trying to make some games for it like a "Raft VR" version and "MarioKart 3D" or "Prison Escape" so we can fully enjoy this nice project.

Thanks for your great work and keep having fun in coding :)

maxime-coutte, 2018-02-05:
If you 3D print arduino and screen controller bumpers you can stick them to a cardboard.

That would be awesome if you create games for the headset! Have you joigned our Fellowship? I’m sure some Fellows could update 3D models :-)

maxime-coutte, 2018-02-08:
Feel free to re open the issue if needed :-)

Closed 2018-02-08.

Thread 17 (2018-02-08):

Case Sensitivity Typo

delp, 2018-02-08:
Ran into a problem today where a user running a non-Due arduino wanted to use this option from the code block. But this won't compile unless "Relativ" is changed to "relativ"

Going to do a pull request.

EDIT: I thought I opened this from a specific line but sorry, I am new to this feature.

delp, 2018-02-08:
Fix here: https://github.com/relativty/Relativ/pull/18

maxime-coutte, 2018-02-08:
I see, great! Thanks ! :)

maxime-coutte, 2018-02-08:
I just merged the pull request, feel free to re open if needed :-)

Closed 2018-02-08.

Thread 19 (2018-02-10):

[Feature Request] support for Unreal Engine

xmak, 2018-02-10:
Do you plan to support Unreal Engine?

I would really like to see this happen and I'm willing to participate with my modest knowledge of UE.

maxime-coutte, 2018-02-10:
We are currently working on stramVR compatibility. But if you want to help with UE that would be awesome !

Feel free to join our Fellowship so maybe you will find some people able to help you.

xmak, 2018-02-10:
How do I join your Fellowship? Do you have some group or forum where you exchange info and ideas?

As I said, my knowledge of C++ coding for UE is pretty modest (I have only worked on some experimental C++ code for network communication and for using MS Kinect in UE), so I would like to find someone who is more experienced to join me on this. I could give a fast track introduction in coding for UE to someone who is interested, and do a share of coding.

I'm planing to make your VR headset here at our local library with help from some of my collegues, so when that works out I can also do the testing.

P.S. You guys rock... your VR headset and the whole idea of making it affordable is one of the most interesting DIY things I have seen lately.

delp, 2018-02-10:
The discord chat where we mostly coordinate is linked at the bottom of the main readme but it's sort of hard to see.

Come about and let's see if we can pair you with someone who wants to work on this.
https://discord.gg/W9VKbjU

Ybalrid, 2018-02-17:
I dug a little bit into your FastVR and WRMHL repositories. As far as I can tell, you are just sending orientation data from the headset to the computer via 250000 baud RS232 (Serial) link from your Arduino board?

It should be easy to make this usable in Unreal, or anything else for that matter.

I agree that a SteamVR integration is probably the ideal route for any new headset on the market (at least until the guys from the Khronos group release [OpenXR](https://www.khronos.org/openxr), since it would make it compatible (at least for getting the images and your current 3 axis tracking) with existing content.

xmak, 2018-03-04:
To close this issue, we have SteamVR support now (via OSVR):

https://github.com/relativty/relativ-core

I haven't tried it but some of the guys did, and it seems to work. I will confirm when I try it with Unreal Engine.

Closed 2018-06-06.

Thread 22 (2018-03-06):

Diopter enhancement

tutle, 2018-03-06:
I'm really very exited to build one, do you think it's easy to modify the structure to add dioptry adjustment ?
Really thanks for this amazing job.

delp, 2018-04-06:
You can try editing the .STL files directly. Or, if you have any experience with 3D modeling, the shape of the headset is easily replaceable by something of your own design, and you can keep the electronics and firmware. If you come up with something like the aforementioned, please fork the repo! Sounds great.

AdmiraalHugo, 2019-04-17:
There have been added 2 new 3D moddels for the headset by the community. Both of them have options for adjustments.

Closed 2019-04-17.

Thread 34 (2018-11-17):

conversion from 'type' to 'type' function is illegal in every OS except Windows!

JustinS-B, 2018-11-17:
Following the **Microsoft Compiler Warning (level 4) C4239**

The **relativ_osvr_plugin/Relativ_OSVR_Plugin.cpp** code fails to compile on any OS except Windows with this error:
```error: cannot bind non-const lvalue reference of type ‘serial::Timeout&’ to an rvalue of type ‘serial::Timeout’ ```

To resolve this, **Кзобьтовскый** created this fix:

 ``` Line 57
				relativ.setTimeout(serial::Timeout::simpleTimeout(1000)); ```

replace the whole of Line 57 with this:

```
				serial::Timeout sto = serial::Timeout::simpleTimeout(1000);
				relativ.setTimeout(sto);
```

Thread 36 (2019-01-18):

Serial Output is all zeros!

kaushal1214, 2019-01-18:
The output on the arduino serial is something like-
`0.00 0.00 0.00 1.00`
And it's not changing at all. Plz help
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

kaushal1214, 2019-01-21:
Hi,
Yes, I'm using MPU6050 and Arduino Due. I think I have connected it correct, because I tested MPU6050 with an example sketch, which are available in arduino IDE. I selected "MPU6050_Raw" example under the "Example from Custom Libraries" category.
At the output I can see the values from gyro changing continuously with motion. It means the MPU6050 and its connections are correct, right?
And I have not used SteamVR till now, as I am stuck with non-functioning of MPU6050.
Hope it helps you to understand my problem.

Thanks

AdmiraalHugo, 2019-01-23:
Hi,

Sorry for the late answer. Yes, that means the MPU6050 is connected good, so that is good to know. Can you contact me on hugo@relativty.net? So I can send you a different code, that might work.

Regards,
Hugo
member Relativty Committee

JustinS-B, 2019-01-24:
Also, we have a specific Linux group on the Relativ Discourse, where we can help you more easily

AdmiraalHugo, 2019-01-24:
If you do have a discord account, you can join our group with this link; https://discord.gg/s9YqY4P

Closed 2019-04-17.

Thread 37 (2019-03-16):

'VectorFloat16' was not declared in this scope

ivanbag, 2019-03-16:
Hello, trying to compile the sketch I get the following error:

**************************************

main:133:9: error: 'VectorFloat16' was not declared in this scope

         VectorFloat16 down;

         ^

main:134:28: error: 'down' was not declared in this scope

         mpu.dmpGetGravity(&down, &q);

                            ^

exit status 1
'VectorFloat16' was not declared in this scope

**************************************

How can I correct it?

Thanks, regards

MicklesC, 2020-06-23:
I know this is over a year old but did you ever figure out a fix for this? I have the same issue.

lunar711, 2020-07-27:
I got it to compile, but the catch is that only Arduino boards that have an internal USB only work (no FTDI or Atmega16U2 as USB controllers). The code compiles if you use Arduino Leonardo and the likes.... (remember to change the "#define INTERRUPT_PIN 2" the pin number '2' to the right Interupt Pin for your board, SDA and SCL depends on what board you use)

```

// Copyright (c) 2017 Relativty

//=============================================================================
// i2cdevlib and MPU6050 are needed: https://github.com/jrowberg/i2cdevlib
// Big thanks to the amazing Jeff Rowberg <3, go check his repo to learn more MPU6050.
//=============================================================================

// I2Cdev and MPU6050 must be installed as libraries, or else the .cpp/.h files
// for both classes must be in the include path of your project

#include "Relativ.h"

#include "I2Cdev.h"

#include "MPU6050_6Axis_MotionApps20.h"

#if I2CDEV_IMPLEMENTATION == I2CDEV_ARDUINO_WIRE
#include "Wire.h"
#endif

MPU6050 mpu;
Relativ relativ;

#define INTERRUPT_PIN 7
// set these to correct for drift - try small values ~0.000001
#define ALPHA 0.f // correction for drift - tilt channel
#define BETA  0.f // correction for drift - yaw channel

// IMU status and control:
bool dmpReady = false;  // true if DMP init was successful
uint8_t mpuIntStatus;
uint8_t devStatus;      // 0 = success, !0 = error
uint16_t packetSize;
uint16_t fifoCount;
uint8_t fifoBuffer[64];

Quaternion q;           // [w, x, y, z]

volatile bool mpuInterrupt = false;     // indicates whether MPU interrupt pin has gone high
void dmpDataReady() {
    mpuInterrupt = true;
}

void setup() {

    #if I2CDEV_IMPLEMENTATION == I2CDEV_ARDUINO_WIRE
        Wire.begin();
        Wire.setClock(400000); // 400kHz I2C clock. Comment this line if having compilation difficulties
    #elif I2CDEV_IMPLEMENTATION == I2CDEV_BUILTIN_FASTWIRE
        Fastwire::setup(400, true);
    #endif

    /**
    * Relativ::startNative() is for 32-bit ARM microconrollers with Native USB like Arduino DUE (recommended)
    * Relativ::start() is for NON-NATIVE USB microcontrollers, like Arduino MEGA, Arduino UNO, etc. (slower)
    */
    relativ.startNative(); //Compile error? change this to relativ.start() if you have an UNO, MEGA, etc...

    mpu.initialize();
    pinMode(INTERRUPT_PIN, INPUT);

    //If you are getting "SerialUSB was not declared" when compiling, change
    //the following line to Serial.println(.......)
    SerialUSB.println(mpu.testConnection() ? F("MPU6050 connection successful") : F("MPU6050 connection failed"));

    // configure the DMP
    devStatus = mpu.dmpInitialize();

    // ==================================
    // supply your own gyro offsets here:
    // ==================================
    // follow procedure here to calibrate offsets https://github.com/kkpoon/CalibrateMPU6050
    mpu.setXGyroOffset(220);
    mpu.setYGyroOffset(76);
    mpu.setZGyroOffset(-85);
    mpu.setZAccelOffset(1788);

    // devStatus if everything worked properly
    if (devStatus == 0) {
        // turn on the DMP, now that it's ready
        mpu.setDMPEnabled(true);

        // enable Arduino interrupt detection
        attachInterrupt(digitalPinToInterrupt(INTERRUPT_PIN), dmpDataReady, RISING);
        mpuIntStatus = mpu.getIntStatus();

        dmpReady = true;

        // get expected DMP packet size for later comparison
        packetSize = mpu.dmpGetFIFOPacketSize();
    } else {
        // ERROR!
    }
}

void loop() {
    // Do nothing if DMP doesn't initialize correctly
    if (!dmpReady) return;

    // wait for MPU interrupt or extra packet(s) to be available
    while (!mpuInterrupt && fifoCount < packetSize) {
    }

    // reset interrupt flag and get INT_STATUS byte
    mpuInterrupt = false;
    mpuIntStatus = mpu.getIntStatus();

    // get current FIFO count
    fifoCount = mpu.getFIFOCount();

    if ((mpuIntStatus & 0x10) || fifoCount == 1024) {
        mpu.resetFIFO();
    }

    // check for interrupt
    else if (mpuIntStatus & 0x02) {
        while (fifoCount < packetSize) fifoCount = mpu.getFIFOCount();
        mpu.getFIFOBytes(fifoBuffer, packetSize);
        fifoCount -= packetSize;

        mpu.dmpGetQuaternion(&q, fifoBuffer);

/**
* Relativ::updateOrientationNative() is for 32-bit ARM core microcontrollers
* with Native USB like Arduino DUE (recommended)
* Relativ::updateOrientation() is for NON-NATIVE USB microcontrollers
* like Arduino Mega, Arduino Uno, etc. (slower)
*/

        // find direction of gravity (down in world frame)
        VectorFloat down;
        mpu.dmpGetGravity(&down, &q);

        // tilt angle is the angle made between world-y and the "up"-vector (just negative of "down")
        float phi = acos( -down.y / down.getMagnitude() );

        // drift due to tilt
        Quaternion d_tilt( cos(phi/2.f), -down.getNormalized().z * sin(phi/2.f), 0.f, down.getNormalized().x * sin(phi/2.f) );

        // TO DO: if magnetometer readings are available, yaw drift can be accounted for
        // int16_t ax_tmp, ay_tmp, az_tmp, gx_tmp, gy_tmp, gz_tmp, mx, my, mz;
        // mpu.getMotion9(ax_tmp, ay_tmp, az_tmp, gx_tmp, gy_tmp, gz_tmp, mx, my, mz);
        // VectorFloat16 magn(float(mx), float(my), float(mz));
        // VectorFloat16 north = magn.rotate(q);
        // float beta = acos( -north.z / north.magnitude() );
        // Quaternion d_yaw( cos(beta/2.f), 0.f, sin(beta/2.f), 0.f );
        Quaternion d_yaw; // just default to identity if no magnetometer is available.

        // COMPLEMENTARY FILTER (YAW CORRECTION * TILT CORRECTION * QUATERNION FROM ABOVE)
        double tilt_correct = -ALPHA * 2.f * acos(d_tilt.w);
        double yaw_correct  = -BETA  * 2.f * acos(d_yaw.w);
        //Quaternion tilt_correction( cos(tilt_correct/2.f), -down.normalize() * sin(tilt_correct/2.f), 0.f, down.normalize().x * sin(tilt_correct/2.f) );

        Quaternion tilt_correction( cos(tilt_correct/2.f), -down.getNormalized().getMagnitude() * sin(tilt_correct/2.f), 0.f, down.getNormalized().x * sin(tilt_correct/2.f) );
        Quaternion yaw_correction( cos(yaw_correct/2.f), 0.f, sin(yaw_correct/2.f), 0.f);

        // qc = yc * tc * q
        Quaternion qc;  //(tilt_correction.w, tilt_correction.x, tilt_correction.y, tilt_correction.z);
        qc = qc.getProduct(yaw_correction);
        qc = qc.getProduct(tilt_correction);
        qc = qc.getProduct(q);

        // report result
        relativ.updateOrientationNative(qc.x, qc.y, qc.z, qc.w, 4);

        //If your microcontroller is non-native usb, change the above line to:
        //relativ.updateOrientation(q.x, q.y, q.z, q.w, 4);
    }
}

```

RasPI-AG-WSG, 2021-07-01:
I have the same problem. I'm using an Arduino DUE. I can't find the VectorFloat16 in any of the used libraries. There's only VectorFloat. But the program doesn't work with the VectorFloat function.

lunar711, 2021-07-01:
Sorry but I've given up on this project ages ago.... If I remember this uses OSVR (Which has been dead for a long time now thanks to SteamVR always updating). This headset only tracks rotation only, like anyother mobile VR headset.....

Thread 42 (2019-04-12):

How do you track the headset position?

off99555, 2019-04-12:
Do you track the headset position using SLAM?
Or you don't track the position, just use rotation from IMU?
I would want to create a tracked headset that works like Mixed Reality tracking quality.

AdmiraalHugo, 2019-04-12:
We use the rotation from the MPU6050 (IMU). We dont track the headset position using SLAM.

Closed 2019-04-13.

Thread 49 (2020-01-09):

"min was not declared in this scope"

lamnoda, 2020-01-09:
In Arduino IDE, when trying to compile the code, and error message, "min was not declared in this scope" pops up. Any Solution?

The Full Error Messages:

Arduino: 1.8.10 (Windows 10), Board: "Generic STM32F103C series, STM32F103C8 (20k RAM. 64k Flash), STM32duino bootloader, 72Mhz (Normal), Smallest (default)"

sketch\I2Cdev_PillPatch.cpp: In static member function 'static int8_t I2Cdev::readBytes(uint8_t, uint8_t, uint8_t, uint8_t*, uint16_t)':

I2Cdev_PillPatch.cpp:276:50: error: 'min' was not declared in this scope

             for (uint8_t k = 0; k < length; k += min<int>(length, BUFFER_LENGTH)) {

                                                  ^

I2Cdev_PillPatch.cpp:276:54: error: expected primary-expression before 'int'

             for (uint8_t k = 0; k < length; k += min<int>(length, BUFFER_LENGTH)) {

                                                      ^

I2Cdev_PillPatch.cpp:276:54: error: expected ')' before 'int'

I2Cdev_PillPatch.cpp:276:57: error: expected unqualified-id before '>' token

             for (uint8_t k = 0; k < length; k += min<int>(length, BUFFER_LENGTH)) {

                                                         ^

I2Cdev_PillPatch.cpp:693:59: error: expected '}' at end of input

 uint16_t I2Cdev::readTimeout = I2CDEV_DEFAULT_READ_TIMEOUT;

                                                           ^

C:\Users\dogsp\Desktop\Relativ-master\STM32\STM32_BlackPill\STM32_BlackPill.ino: In function 'void setup()':

STM32_BlackPill:48:14: error: 'class TwoWire' has no member named 'setSDA'

         Wire.setSDA(PB7);

              ^

STM32_BlackPill:49:14: error: 'class TwoWire' has no member named 'setSCL'

         Wire.setSCL(PB6);

              ^

Multiple libraries were found for "Wire.h"
 Used: C:\Users\dogsp\AppData\Local\Arduino15\packages\stm32duino\hardware\STM32F1\2019.12.31\libraries\Wire
 Not used: C:\Users\dogsp\AppData\Local\Arduino15\packages\stm32duino\hardware\STM32F1\2019.12.31\libraries\WireSlave
exit status 1
'min' was not declared in this scope

This report would have more information with
"Show verbose output during compilation"
option enabled in File -> Preferences.

fa1ke5, 2020-01-12:
You need selecting proper sdk and board in arduino, read wiki

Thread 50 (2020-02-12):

[FEATERE REQUEST] Compatible SteamVR games, controllers and laser pointer support

Sgw32, 2020-02-12:
Hi,

Built my own headset! Looks pretty good and works. Thanks a lot for this project.

Anyway, I am unable to play most of Steam games with this setup:

 - Relativ headset
 - Xbox360-compatible controller

The laser beam just do not appear even in SteamVR Home application. It is also impossible to navigate in a dashboard. What games can you advise for your headset? I've found an interesting space simulator - but it is only game I've found.
Either game is playable through mouse/keyboard/joystick, either it is connected to SteamVR and it is impossible to play the game. I just see what's aroung in this headset - which is pretty good, but I am interested in making it playable. So, I think, users of the Headset need from you:
1) List of compatible games
2) List of compatible tracker and controller hardware for using with SteamVR and Relativ.

JulianGro, 2020-09-21:
I am pretty sure VRChat works with just an xbox controller. (Windows)
Vircadia seems to work with a keyboard, so I would assume an xbox controller would work as well. Nonetheless Vircadia is an open source project as well, so it might be a good fit.

okawo80085, 2020-09-21:
this was caused by the lack of hmd's bindings, and im guessing by osvr being old af

but now relativty has its own steamvr driver, the hmd's laser pointer should work now(with a controller per say)

if you still find some game not working with it by all means let me know

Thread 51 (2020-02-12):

[BUG] I2C connection is unstable

Sgw32, 2020-02-12:
**The bug**

Just connect STM32 blue pill with MPU6050 sensor. It will work pretty good, but sometimes, after some small shakes, or SteamVR lags it just hangs. Reboot causes USB device disconnect(which is an another issue), but still, after the reboot the connection is not established.

**To Reproduce**
Steps to reproduce the behavior:
1. Start any SteamVR game with a headset and a high load
2. Shake the headset and rotate it
3. The orientation will hang.
4. Exit SteamVR and OSVR driver
5. Test Serial connection by opening the corresponding port
6. If it opens, but there is no data it means I2C hang.

**Proposed solution**

Check I2C for timeout errors, and if timeout happen, reset the I2C bus. You can find the implementation of this algorithm in Ardupilot repository, as an example. I have a PoC code which resets the bus at reset, can share it.

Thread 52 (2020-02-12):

[FEATERE REQUEST] CH340 or FTDI serial connection

Sgw32, 2020-02-12:
**Is your feature request related to a problem? Please describe.**
it is related to the potential unstability of USB STM32 Serial drivers

**Describe the solution you'd like**

I recommend you using the CH340 or FTDI serial dongles (or separate PCBs) because they have MUCH more improved stability, I have an experience of working with CH340 device, which was connected to a Windows machine for a month.
Your arduino code could probably be left unchanged.
Check Aliexpress for cheap serial converters.

okawo80085, 2020-09-21:
relativty moved to using hid for communication

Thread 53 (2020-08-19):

[FEATERE REQUEST] Use correct industry terminology for what this project is developing

ObsidianX, 2020-08-19:
**Is your feature request related to a problem? Please describe.**
This project is using the wrong terminology in regards to the tracking technology being developed.  The sensors used are not "6DoF" or "9DoF" as described.  Using correct terminology will clear up a lot of confusion around the project's current goals and released software.

**Describe the solution you'd like**
"#DoF" stands for "Degrees of Freedom" and is a term used to describe how the user can move about in VR.  The tracking system being developed here only provides *3DoF*: Pitch, Yaw, Roll.

6DoF means that on top of rotation the user is also able to translate around the VR space in X, Y, Z directions.  Therefore there are now 6 degrees of freedom: Pitch, Yaw, Roll, X, Y, Z.  As far as I can figure out there aren't additional degrees in which to unlock to achieve "9DoF".

The sensors you're developing are multi-_axis_ sensors in the pursuit of higher quality "3DoF" tracking.  The 3 sensors utilized in this project provide a 9-_Axis_ tracking solution and only provides more accurate rotational tracking.

**Additional context**
https://creator.oculus.com/learn/vr-glossary/

siddacious, 2020-09-11:
I appreciate the intent to clarify and standardize terminology however IMHO you are mostly right but not completely right. My only nit-pick is  The MPU6050 includes two three-axis sensors and support for a third.

The **accelerometer** measures linear acceleration/translation and the *gyroscope** measures angular velocity. That's 6 degrees of freedom as you defined it.

I agree that unless they've figured out how to fold spacetime, Invensense and everyone else claiming to have a "9DoF" sensor is letting their marketing team have a bit too much leeway for my taste. Magnetometers are sometimes used to address drift in angular velocity but extrapolating from what you said, that's still only 6-DoF.

With regards to my larger _agreement_, only just now having seen this project I'm going to assume that they're using the 6-DoF IMU/Gyro+Accel to provide 3-DoF tracking, so they should be explicit and clear about that.

capnmidnight, 2020-09-21:
It's "standard" within the IMU market to list the DOF as a sum of all the DOFs of the individual sensing elements. Accelerometer+gyroscope+magnetometer ICs are *always* called 9-DOF.

VR headsets should be labeled according to the degrees the expose to the user. Using a single IMU, you'll only be able to achieve 3-DOF.

capnmidnight, 2020-09-21:
That said, have you considered using the Inte RealSense T265 tracking module for true 6-DOF tracking, and if so, what was your determination?

https://www.intelrealsense.com/tracking-camera-t265/

siddacious, 2020-09-29:
I agree with @capnmidnight that while it might grind my gears slightly, 9-DOF is the commonly used term for such devices. To me this means that if you feel the need to call out the dof-ness of the sensors, 9-DOF is "correct" insofar as it effectively communicates what they are to people that are familiar. If this is worth mentioning is not something I have a stake in. Though it might confuse laypeople.

The tracking solution however is, as I think we all agree, 3-DOF.

ObsidianX, 2020-09-29:
Given the above arguments I think it ultimately depends on the context.  This project is developing a VR headset and the end result is a 3-DoF or 6-DoF product.  The IMUs, cameras, lighthouse sensors, etc, used to achieve that isn't relevant to the project's deliverables and since this is going to hopefully be listed among all other VR headsets should standardize the terminology used to describe the product's features on the rest of the VR industry.

_As a side note I feel given the meaning of a "degree of freedom" it's incorrect for an IMU to use DoF to describe an axis, but that's not relevant to this project ;)_

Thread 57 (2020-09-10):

Compiling Driver on UNIX-like Operating Systems

oxr463, 2020-09-10:
I would suggest using CMake along with G++ for compiling the native code, instead of the MSVC project files used currently.

okawo80085, 2021-01-07:
that would be nice, and it is possible with minor code modification, but starting somewhere from steamvr 1.15.x the display component that this driver uses was broken and is still(to my knowledge) not working on linux, it used to work fine, why it's not working anymore? beats me, could be that that particular display component is just slowly loosing support and moving to a different display component will fix it, but thats waaaaaaaaaaaaaay harder to do, we tried to do that, but it didn't work, will try again, but not in the near future

so yeah, rn steamvr is kinda broken on linux for this driver, unless valve fixes steamvr idk, wait and see ¯\_(ツ)_/¯

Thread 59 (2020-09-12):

Lenses not available any more ?

vospascal, 2020-09-12:
No store behind the lens might be an idea to make a list of stores And places where you can source the components not just one link for every component

ezar, 2020-10-04:
Same here!

okawo80085, 2020-10-06:
I mean you can make this list yourself if you want  to

isaaclepes, 2022-08-26:
Yeah, it's hard to find a seller for 40mm dia. 50mm focal len. lenses.. all of them seem to be 42mm.  Since the focal length is what's most important, just get as close to the diameter as you can and modify the 3d model to hold the new diameter lenses.

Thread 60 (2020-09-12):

LCD screen type

renzenicolai, 2020-09-12:
Not a question or issue, but a starting point for developing a more integrated solution: the displays you're using are Sharp LS029B3SX02 LCDs (https://www.panelook.com/LS029B3SX02_Sharp_2.9_LCM_overview_27997.html). Datasheet: https://ds0.me/ds/LS029B3SX02.pdf

Maybe this information could serve as a starting point for someone to develop a proper integrated Arduino + displayport-over-usb-c to MIPI converter PCB for these displays.

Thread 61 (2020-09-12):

Hardware license

renzenicolai, 2020-09-12:
You've currently chosen to put the GPLv3 license on the project. The GPL is suitable for software, but less so for hardware. In addition please consider how using the GPL essentially complicates any commerical use of your creation. While this indeed keeps your project out of the hands of commercial companies who could run away with the idea it also blocks anyone from creating a proper product based on your work.

What's your end goal for the project? Creating a commercial success for yourself or creating an open VR headset that's made available commercially by several companies?

Anyhow please consider using a permissive license like MIT or BSD for the software and a truely OSHW license like the CERN–OHL-P.

Olm-e, 2020-09-13:
I agree the hardware needs proper OSHW licence

but for the software : GPL does not blocks anyone to create a proper product from here, on the contrary : it would permit a sane redistribution of the code and ensure buyers have all the needed rights on it as companies could not close it down to sell it. It's a good selling point imho. so keep it open and libre ;)

AmmarkoV, 2020-09-15:
GPL3 prevents TiVo-isation ( https://en.wikipedia.org/wiki/Tivoization ) which is a valid concern for a hardware project. If someone wants to create a commercial use its fine as long as he provides what he received as free and open source in the same way.

VinnyCordeiro, 2020-09-15:
GPL is not against commercial use of code/hardware. GPL is against use of code/hardware in a way that prevents the users to study the code and make changes by himself/herself.

If a company wants to make a product with full control of the IP then they should expend their money on R&D and develop their own products, not using open source projects, add some changes, and then lock the users out.

truedat101, 2020-11-26:
Agree 100% with @renzenicolai .   The notion that every business enterprise wants to pillage open source and pull a Linksys/Tivo/MSFT , is wrong.  Imagine an EDU-tech company that is attempting to build platforms for covid era distance learning.  They won't have the expertise to necessarily  build VR HW from scratch, nor the budgets to fund years of effort.   And they may not have the experienced resources to successfully contribute back to open source.  But they might be willing to fund/sponsor development.

Speaking not from a podium of ideology, but as someone who has worked with companies who attempt to take proprietary their own proprietary work into open source, there are numerous challenges to GPLv2 or v3 that is 99% radioactive for a legitimate business enterprise wanting to build on top of work developed by a 3rd party.  Companies do it and manage to comply, but most of the time this will be in modifying an existing hardware driver or some other aspect of a linux kernel.  Attempts to build a viable product around a GPLv2/v3 licensed hw/sw will usually get shot down by the legal team on the basis that many in-house legal teams just don't understand open source licensing well and don't like the terms of GPLv2/v3.

There is a secondary challenge around the question of patents, and GPLv2 does not make an explicit patent grant, while GPLv3 does.  That said, GPLv3 does make an explicit grant, however there is nothing stopping someone from making a claim on infringement and it offers no protection to the recipient of the covered sw/hw.

Can I propose dual license as an option?  The copyright holder(s) always have an option to offer a proprietary license or alternative open source license (assuming all copyright holders are contributors and they all agree to this).  GPL makes the decision to try out/prototype software/hardware very easy, however, companies who have a legal team that blocks exposure to these licenses, will want to get a different license.  And they will usually pay for this right, at which point the copyright holder can attach additional terms which may achieve the same goal in preventing Tivo-isation without the licensee worrying about the implications of copyleft provisions might have on the greater work they intend to create.  Companies will also want to seek a more detailed set of terms around patent grants if applicable.

A dual license/alternative license doesn't have to go into the license file and can be made available upon inquiry.  Personally I prefer an option of GPL or academic license explicitly in the LICENSE file , and this still encourages contributors to then be compliant with both licenses if they wish to provide patches / pull requests.

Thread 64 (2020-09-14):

Single display instead of stereoscopic

errorenousReport, 2020-09-14:
I there a way to create this with a large single display instead of dual displays?  I know many people desire stereoscopic, but I would rather have one larger display instead of locking my eyes into a little lens.  The 6dof control and head tracking I feel would be more immersive without a limited stereoscopic display and this open source project would be a good testing ground.

okawo80085, 2020-09-21:
with the current design it treats that "dual" display as a single display, windows sees it as one, its separated into 2 panels only physically, the software sees it as 1 whole display. also current software setup *can only* work with a single display, as in steamvr's vr view will be only visible on 1 display

and about
> The 6dof control and head tracking I feel would be more immersive without a limited stereoscopic display and this open source project would be a good testing ground.

what might you mean by that?

bc either way you will get a stereoscopic image(2 eyes, 2 different camera views), for vr you don't get to choose

also how is this setup limiting??? if htc, valve, oculus and others use 2 panel displays maybe there is a good reason for that

capnmidnight, 2020-09-21:
I think OP is talking about having a single, large view, like a monitor attached to your head, with no stereoscopic rendering, not just the number of display modules inside the headset.

No VR headset on the market does this for a very good reason: focal distance.

If you try to make a lens system that focuses both eyes individually onto a single, small display panel, you end up with *huge* amounts of lens distortion, such that you'll never get both eyes lined up on the display panel correctly. You'll have all of the pixels of the display going into each eye, but the relative position of each pixel will be massively out of place and you'll just end up with double vision.

If you forgo the lenses completely, you have to push the display out far away from the face. This increases the angular momentum of the display, meaning whipping your head around gets a lot harder and a lot more tiring. Also, just holding your head up gets a lot more tiring, with or without a counterbalance. Plus, to get a full field of view, you'd have to use a much larger display, which exacerbates all of those weight issues.

No, you can't do a single, monoscopic view headset with the hopes of achieving wider FOV. You'll always end up needing some kind of lens system, which will always split the view between different halves of the display module (or two separate display modules). At which point, you might as well make it stereoscopic.

okawo80085, 2020-09-21:
and none of the frame delivery components available for drivers support monoscopic views

marcdraco, 2021-05-03:
As a movie guy (games are a secondary consideration for me, an important one though) I can see what the OP's getting at but I think they misunderstand how binocular vision works.

@errorenousReport We need lenses on a headset for essentially the same reason as we need them on, say a microscope. Our eyes just can't focus on objects a few mm in front of them without creating serious eye strain. Try looking at something and moving it closer and closer to your head and you'll see that as things get closer it's difficult and eventually impossible to focus on it.

Binoculars and dissection microscopes have two eyepieces for the same reason. The (fresnel) lenses do in our current HMDs - they move the focal point far enough into the distance (as our eyes see it) so they are able to focus without  eye strain. It's doable with glass lenses but they cost a lot more and even with the best high-refractive index optical glass we have today, they will be considerably thicker and much heavier too.

@capnmidnight sums it up well but just to add to that it's important to realise that our brains don't see the world as a flat plane either. We see a flat plane because it's, well, flat. Our brain figures that out when it creates the perception of what we're looking at (similarly it also focuses across our entire field of vision but makes it *appear* to us that everything is in focus). In fact, our world (to our eyes) is upside down, but our brains flip it the right way up. There's a lot of neuroscience around this that I won't delve into here but it's damn clever stuff.

The Nintento 3Ds managed something using a single display with (I think, a fresnel) with fairly poor results - but that was for kids who were more interested in the novelty. Perhaps this is what you were thinking about? Or maybe you're thinking along the lines of HSBS that's used in el-cheapo headsets like Google cardboard (more of that in a moment).

There is a _potential_ solution to all of this (in research/academia) but there's no consumer version that I'm aware of as yet and may never be one. As I recall it involves using lasers to "fire" light rays directly into our eyes. Unlike the "high-power" lasers that can damage the eye, these use visible light at a very low power and are directed so they enter the eye and hit the retina already in focus. Rather like cutting out the middle man. It sounds like science fiction and I won't pretend that I understand it myself - although I suspect the military already uses something similar for HMDs.

For now, we're pretty much stuck with the available technology - because if something better appears, it will likely be subject to patents, crippling license fees and only be practical for the big guys. In Open Source, we have to innovate but optics and optical electronics are (again) something that only companies with bottomless pockets are able to dabble in.

What I would like to see (and Open Source can innovate here a little) is moving some of the weight elsewhere on the HMD. I think Panasonic demonstrated something recently but that's still in development. In essence that appeared to use two circular TFTs (square would work just as well) with lenses over each eye as in current designs but more of a John Lennon look. It appeared from the glance I got that all the electronics other than the displays had been moved away from the face - which is really the problem most of us have with HMDs that the b*ggers are so darn heavy.

I have one of those nasty HMDs that you drop a phone into - Google cardboard sort of thing and as is, it's quite lightweight despite being sloppily designed. Put a phone in it (single display) and it's unusable after a few minutes because it falls off my face.

I don't think Relativity has this issue because it's tethered (correct me please if I'm wrong) but if the team is going to look at something wireless like the Oculus Quest/Go/Quest 2 (etc.) then that battery is going to be a massive problem. I guess this is a discussion for elsewhere though.

Stay safe everyone!

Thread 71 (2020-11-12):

About the driver

Jianglf19, 2020-11-12:
Turn on steamvr, no matter whether my gyroscope is moving or not, the screen will jitter violently. I thought the gyroscope was broken, but the data on the serial port monitoring tool is normal
From Google Translate

okawo80085, 2020-11-12:
what sensor are you using?

Jianglf19, 2020-11-14:
Is gy9250(mpu9250 chip)+arduino due

Jianglf19, 2020-11-14:
> 您正在使用什么传感器？
>
> 您正在使用什么arduino固件？

Is gy_9250(mpu9250 chip) and arduino due

okawo80085, 2020-11-14:
im guessing you used arduino code from `Relativty/Relativty_Firmware/MP9250-HID/MP9250-HID.ino`

if you're using that arduino code, you *have* to change this to `false` in the driver config
```json
...
"hmdIMUdmpPackets":  false,
...
```

Jianglf19, 2020-11-14:
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

Thank you for your help, it can be used normally

Closed 2020-11-16.

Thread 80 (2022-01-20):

New headset?

Kreyren, 2022-01-20:
> We are starting a new company called Unai, building a new standalone VR headset from the ground-up and, alongside, the OS and Virtual World powering it. Our end goal is to solve immersiveness. This poses challenges in fields ranging from optics, computer vision, electrical design, low-level OS, game engine and many more.

I plan on reworking the design for contribution, are you going to release the new headset or can i get an access to pre-release version?

CC @maxim-xyz

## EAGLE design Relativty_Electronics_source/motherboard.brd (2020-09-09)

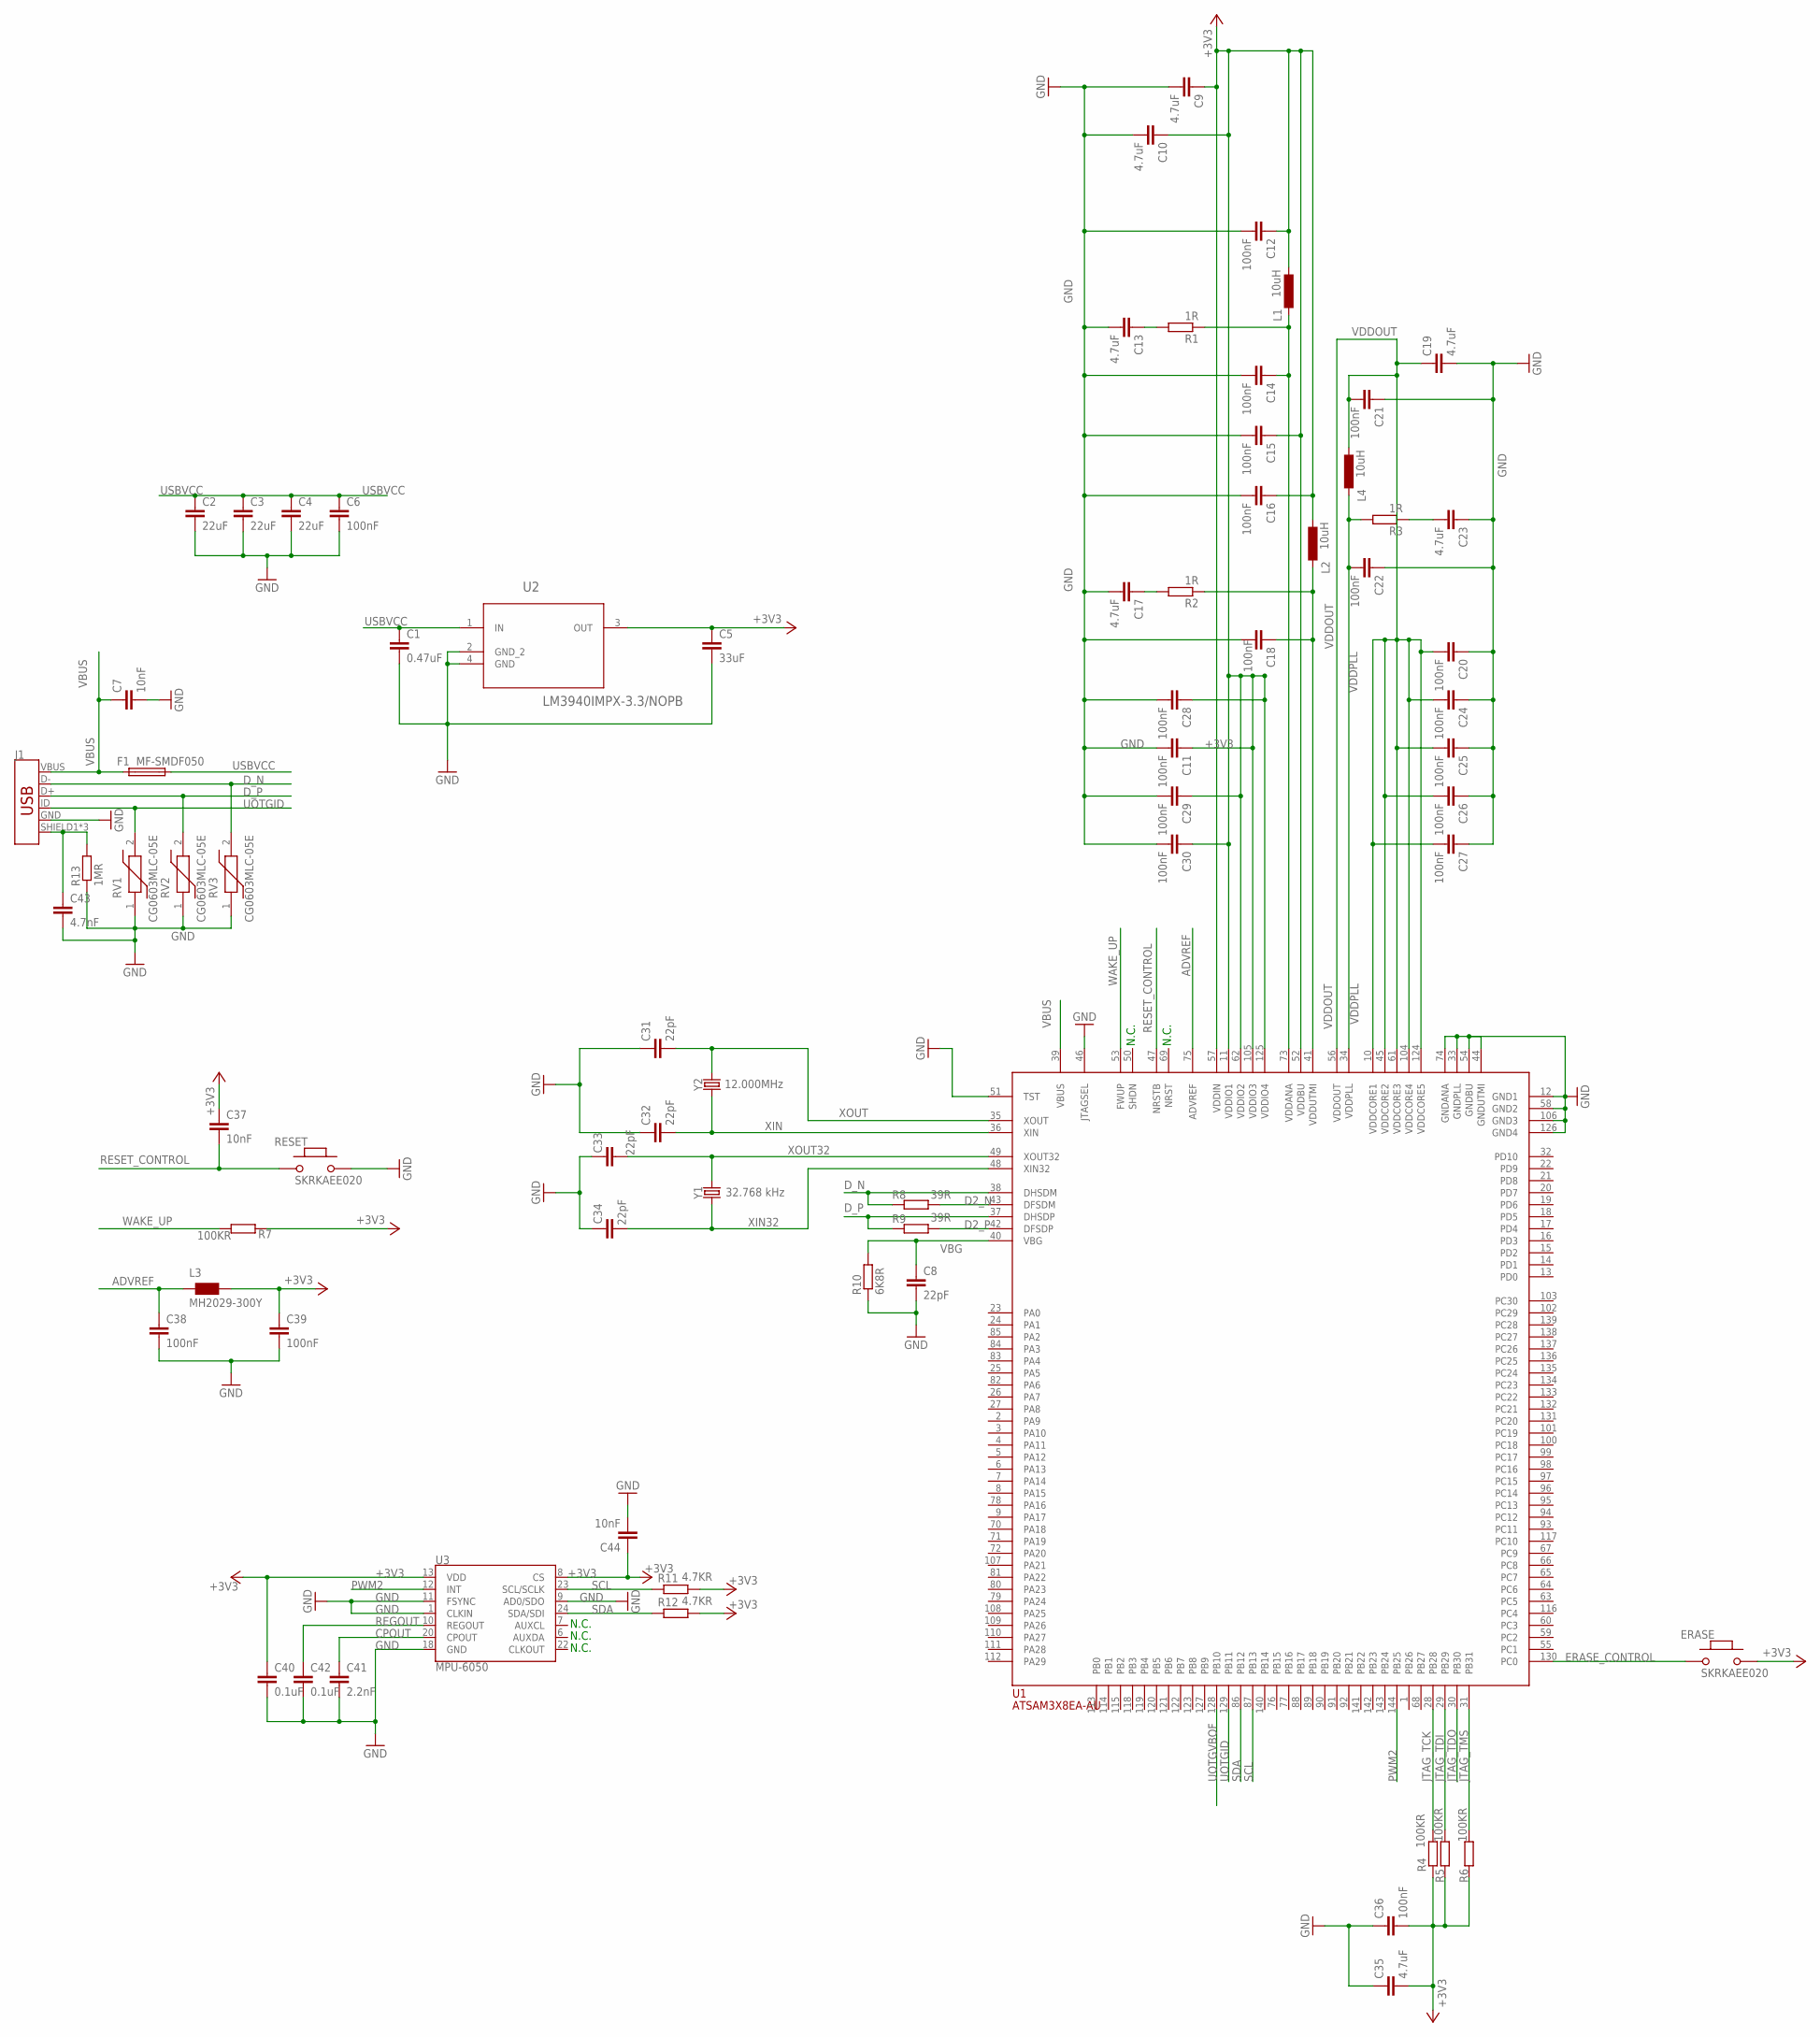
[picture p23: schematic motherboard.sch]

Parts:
C1: 0.47uF; C0805
C2, C3, C4: 22uF; C1206
C5: 33uF; C1206
C6, C11, C12, C14, C15, C16, C20, C21, C22, C24, C25, C26, C27, C28, C29, C30, C36, C38, C39: 100nF; C0402
C7, C37, C44: 10nF; C0402
C8, C31, C32, C33, C34: 22pF; C0402
C9, C10, C13, C17, C19, C23, C35: 4.7uF; C0805
C18: 100nF; C0201
C40, C42: 0.1uF; C0402
C41: 2.2nF; C0402
C43: 4.7nF; C0402
ERASE: SKRKAEE020; SOD4829X200
F1: MF-SMDF050
J1: USB_MICRO-B_FEMALE-SMT; USB-B-MICRO-SMD
L1, L2, L4: 10uH; L2012C
L3: MH2029-300Y; 2012-EU
R1, R2, R3: 1R; R0402
R4, R5, R6, R7: 100KR; R0603
R8, R9: 39R; R0402
R10: 6K8R; R2012
R11, R12: 4.7KR; R0805
R13: 1MR; R1206
RESET: SKRKAEE020; SOD4829X200
RV1, RV2, RV3: CG0603MLC-05E; VARC1608X55N
U1: ATSAM3X8EA-AU; LQFP144
U2: LM3940IMPX-3.3/NOPB; SOT230P696X180-4N
U3: MPU-6050; QFN-24-EP
Y1: 32.768 kHz; CRYSTAL-SMD-3.2X1.5MM
Y2: 12.000MHz; CRYSTAL-SMD-3.2X2.5MM

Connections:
+3V3: C5.1, C9.1, C10.1, C11.1, C12.1, C15.1, C16.1, C28.1, C29.1, C30.1, C35.2, C36.2, C37.1, C39.1, C40.1, C44.1, ERASE.2, L1.1, L2.1, L3.2, R4.1, R5.1, R6.1, R7.1, R11.2, R12.2, U1.11 (VDDIO1), U1.52 (VDDBU), U1.57 (VDDIN), U1.62 (VDDIO2), U1.105 (VDDIO3), U1.125 (VDDIO4), U2.3 (OUT), U3.8 (CS), U3.13 (VDD)
ADVREF: C38.1, L3.1, U1.75 (ADVREF)
CPOUT: C41.1, U3.20 (CPOUT)
D2_N: R8.2, U1.43 (DFSDM)
D2_P: R9.2, U1.42 (DFSDP)
D_N: J1.D-, R8.1, RV3.2, U1.38 (DHSDM)
D_P: J1.D+, R9.1, RV2.2, U1.37 (DHSDP)
ERASE_CONTROL: ERASE.1, U1.130 (PC0)
GND: C1.2, C2.2, C3.2, C4.2, C5.2, C6.2, C7.2, C8.2, C9.2, C10.2, C11.2, C12.2, C13.2, C14.2, C15.2, C16.2, C17.2, C18.2, C19.2, C20.1, C21.1, C22.1, C23.1, C24.1, C25.1, C26.1, C27.1, C28.2, C29.2, C30.2, C31.1, C32.1, C33.1, C34.1, C35.1, C36.1, C38.2, C39.2, C40.2, C41.2, C42.2, C43.2, C44.2, J1.GND, R10.1, R13.1, RESET.2, RV1.1, RV2.1, RV3.1, U1.12 (GND1), U1.33 (GNDPLL), U1.44 (GNDUTMI), U1.46 (JTAGSEL), U1.51 (TST), U1.54 (GNDBU), U1.58 (GND2), U1.74 (GNDANA), U1.106 (GND3), U1.126 (GND4), U2.2 (GND_2), U2.4 (GND), U3.1 (CLKIN), U3.9 (AD0/SDO), U3.11 (FSYNC), U3.18 (GND)
JTAG_TCK: R4.2, U1.28 (PB28)
JTAG_TDI: R5.2, U1.29 (PB29)
JTAG_TDO: U1.30 (PB30)
JTAG_TMS: R6.2, U1.31 (PB31)
unnamed: C43.1, J1.SHIELD1 (SHIELD), J1.SHIELD2 (SHIELD), J1.SHIELD3 (SHIELD), R13.2
unnamed: C13.1, R1.2
unnamed: C17.1, R2.2
unnamed: C23.2, R3.1
unnamed: C14.1, L1.2, R1.1, U1.73 (VDDANA)
unnamed: C18.1, L2.2, R2.1, U1.41 (VDDUTMI)
PWM2: U1.144 (PB25), U3.12 (INT)
REGOUT: C42.1, U3.10 (REGOUT)
RESET_CONTROL: C37.2, RESET.1, U1.47 (NRSTB)
SCL: R11.1, U1.87 (PB13), U3.23 (SCL/SCLK)
SDA: R12.1, U1.86 (PB12), U3.24 (SDA/SDI)
UOTGID: J1.ID, RV1.2, U1.129 (PB11)
UOTGVBOF: U1.128 (PB10)
USBVCC: C1.1, C2.1, C3.1, C4.1, C6.1, F1.2, U2.1 (IN)
VBG: C8.1, R10.2, U1.40 (VBG)
VBUS: C7.1, F1.1, J1.VBUS, U1.39 (VBUS)
VDDOUT: C19.1, C20.2, C21.2, C24.2, C25.2, C26.2, C27.2, L4.1, U1.10 (VDDCORE1), U1.45 (VDDCORE2), U1.56 (VDDOUT), U1.61 (VDDCORE3), U1.104 (VDDCORE4), U1.124 (VDDCORE5)
VDDPLL: C22.2, L4.2, R3.2, U1.34 (VDDPLL)
WAKE_UP: R7.2, U1.53 (FWUP)
XIN: C32.2, U1.36 (XIN), Y2.1
XIN32: C34.2, U1.48 (XIN32), Y1.P$1 (1)
XOUT: C31.2, U1.35 (XOUT), Y2.3 (2)
XOUT32: C33.2, U1.49 (XOUT32), Y1.P$2 (2)

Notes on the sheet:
N.C.

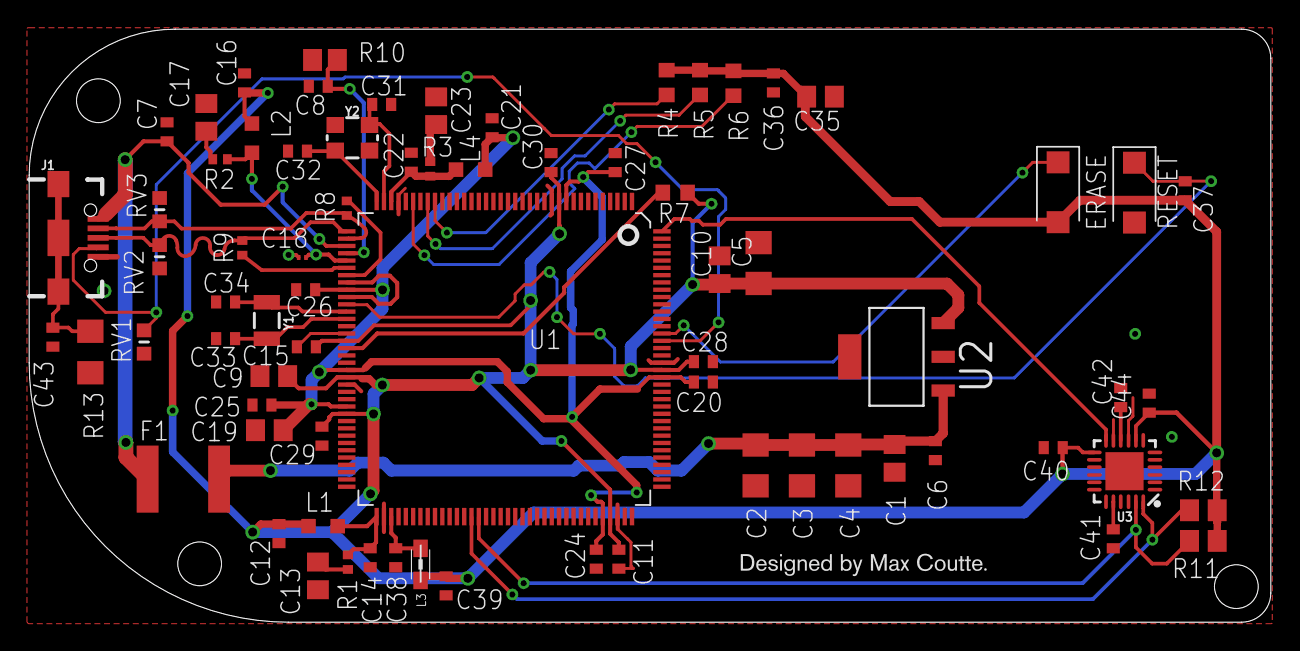
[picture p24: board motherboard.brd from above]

Board: 2 copper layers, 85.1 x 40.6 mm, 73 parts (0 on the bottom side), 34 nets.

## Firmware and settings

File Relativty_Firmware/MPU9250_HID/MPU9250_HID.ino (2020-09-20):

/************************************************************
MPU9250_DMP_Quaternion
 Quaternion example for MPU-9250 DMP Arduino Library 
Jim Lindblom @ SparkFun Electronics
original creation date: November 23, 2016
https://github.com/sparkfun/SparkFun_MPU9250_DMP_Arduino_Library

The MPU-9250's digital motion processor (DMP) can calculate
four unit quaternions, which can be used to represent the
rotation of an object.

This exmaple demonstrates how to configure the DMP to 
calculate quaternions, and prints them out to the serial
monitor. It also calculates pitch, roll, and yaw from those
values.

Development environment specifics:
Arduino IDE 1.6.12
SparkFun 9DoF Razor IMU M0

Supported Platforms:
- ATSAMD21 (Arduino Zero, SparkFun SAMD21 Breakouts)

CHANGES by Gabor Nemeth 2020
I'm using this for VR head tracking with the Relativ-OSVR plugin.
*************************************************************/
#include <SparkFunMPU9250-DMP.h>
#include "Wire.h"
#include "I2Cdev.h"

#include "HID.h"
#if !defined(_USING_HID)
#error "Using legacy HID core (non pluggable)"
#endif

static const uint8_t _hidReportDescriptor[] PROGMEM = {
 0x06, 0x00, 0xff,         // USAGE_PAGE (vendor defined)
    0x09, 0x00,         // USAGE (Undefined)
    0xa1, 0x01,         // COLLECTION (Application)
    0x15, 0x00,         //   LOGICAL_MINIMUM (0)
    0x26, 0xff, 0x00,   //   LOGICAL_MAXIMUM (255)
    0x85, 0x01,         //   REPORT_ID (1)
    0x75, 0x08,         //   REPORT_SIZE (8)
    
    0x95, 0x3f,         //   REPORT_COUNT (63)
    
    0x09, 0x00,         //   USAGE (Undefined)
    0x81, 0x02,         //   INPUT (Data,Var,Abs) - to the host
    0xc0           
};

//#define SerialPort SerialUSB

MPU9250_DMP imu;
int i = 0;
//float quat[4];

void setup() 
{
  static HIDSubDescriptor node (_hidReportDescriptor, sizeof(_hidReportDescriptor));
  HID().AppendDescriptor(&node);

  //Serial.begin(115200);
  Wire.begin();
  Wire.setClock(2000000);

  delay(2000);

  // Call imu.begin() to verify communication and initialize
  if (imu.begin() != INV_SUCCESS)
  {
    while (1)
    {
      Serial.println("Unable to communicate with MPU-9250");
      Serial.println("Check connections, and try again.");
      Serial.println();
      delay(5000);
    }
  }
  
  imu.dmpBegin(DMP_FEATURE_6X_LP_QUAT | // Enable 6-axis quat
               DMP_FEATURE_GYRO_CAL, // Use gyro calibration
              60); // Set DMP FIFO rate to 10 Hz
  // DMP_FEATURE_LP_QUAT can also be used. It uses the 
  // accelerometer in low-power mode to estimate quat's.
  // DMP_FEATURE_LP_QUAT and 6X_LP_QUAT are mutually exclusive
}

void loop() 
{
  // Check for new data in the FIFO
  if ( imu.fifoAvailable() )
  {
    // Use dmpUpdateFifo to update the ax, gx, mx, etc. values
    if ( imu.dmpUpdateFifo() == INV_SUCCESS)
    {
      // computeEulerAngles can be used -- after updating the
      // quaternion values -- to estimate roll, pitch, and yaw
      imu.computeEulerAngles();
      printIMUData();
    }
  }
}

void printIMUData(void)
{  
  // After calling dmpUpdateFifo() the ax, gx, mx, etc. values
  // are all updated.
  // Quaternion values are, by default, stored in Q30 long
  // format. calcQuat turns them into a float between -1 and 1
  /*
  quat[0] = imu.calcQuat(imu.qw);
  quat[1] = imu.calcQuat(imu.qx);
  quat[2] = imu.calcQuat(imu.qy);
  quat[3] = imu.calcQuat(imu.qz);
  */
  float quat[] = {-0.1234, 0.1234, 0.5678, -0.5678};
  HID().SendReport(1,(uint8_t*)quat,sizeof(quat));

}

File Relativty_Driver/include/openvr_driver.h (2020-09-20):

#pragma once

// openvr_driver.h
//========= Copyright Valve Corporation ============//
// Dynamically generated file. Do not modify this file directly.

#ifndef _OPENVR_DRIVER_API
#define _OPENVR_DRIVER_API

#include <stdint.h>



// version.h
namespace vr
{
	static const uint32_t k_nSteamVRVersionMajor = 1;
	static const uint32_t k_nSteamVRVersionMinor = 14;
	static const uint32_t k_nSteamVRVersionBuild = 15;
} // namespace vr

// vrtypes.h
#ifndef _INCLUDE_VRTYPES_H
#define _INCLUDE_VRTYPES_H

// Forward declarations to avoid requiring vulkan.h
struct VkDevice_T;
struct VkPhysicalDevice_T;
struct VkInstance_T;
struct VkQueue_T;

// Forward declarations to avoid requiring d3d12.h
struct ID3D12Resource;
struct ID3D12CommandQueue;

namespace vr
{
#pragma pack( push, 8 )

/** A handle for a spatial anchor.  This handle is only valid during the session it was created in.
* Anchors that live beyond one session should be saved by their string descriptors. */
typedef uint32_t SpatialAnchorHandle_t;

typedef void* glSharedTextureHandle_t;
typedef int32_t glInt_t;
typedef uint32_t glUInt_t;

// right-handed system
// +y is up
// +x is to the right
// -z is forward
// Distance unit is  meters
struct HmdMatrix34_t
{
	float m[3][4];
};

struct HmdMatrix33_t
{
	float m[3][3];
};

struct HmdMatrix44_t
{
	float m[4][4];
};

struct HmdVector3_t
{
	float v[3];
};

struct HmdVector4_t
{
	float v[4];
};

struct HmdVector3d_t
{
	double v[3];
};

struct HmdVector2_t
{
	float v[2];
};

struct HmdQuaternion_t
{
	double w, x, y, z;
};

struct HmdQuaternionf_t
{
	float w, x, y, z;
};

struct HmdColor_t
{
	float r, g, b, a;
};

struct HmdQuad_t
{
	HmdVector3_t vCorners[ 4 ];
};

struct HmdRect2_t
{
	HmdVector2_t vTopLeft;
	HmdVector2_t vBottomRight;
};

/** Used to return the post-distortion UVs for each color channel. 
* UVs range from 0 to 1 with 0,0 in the upper left corner of the 
* source render target. The 0,0 to 1,1 range covers a single eye. */
struct DistortionCoordinates_t
{
	float rfRed[2];
	float rfGreen[2];
	float rfBlue[2];
};

enum EVREye
{
	Eye_Left = 0,
	Eye_Right = 1
};

enum ETextureType
{
	TextureType_Invalid = -1, // Handle has been invalidated
	TextureType_DirectX = 0, // Handle is an ID3D11Texture
	TextureType_OpenGL = 1,  // Handle is an OpenGL texture name or an OpenGL render buffer name, depending on submit flags
	TextureType_Vulkan = 2, // Handle is a pointer to a VRVulkanTextureData_t structure
	TextureType_IOSurface = 3, // Handle is a macOS cross-process-sharable IOSurfaceRef, deprecated in favor of TextureType_Metal on supported platforms
	TextureType_DirectX12 = 4, // Handle is a pointer to a D3D12TextureData_t structure
	TextureType_DXGISharedHandle = 5, // Handle is a HANDLE DXGI share handle, only supported for Overlay render targets. 
									  // this texture is used directly by our renderer, so only perform atomic (copyresource or resolve) on it
	TextureType_Metal = 6, // Handle is a MTLTexture conforming to the MTLSharedTexture protocol. Textures submitted to IVRCompositor::Submit which
						   // are of type MTLTextureType2DArray assume layer 0 is the left eye texture (vr::EVREye::Eye_left), layer 1 is the right
						   // eye texture (vr::EVREye::Eye_Right)
};

enum EColorSpace
{
	ColorSpace_Auto = 0,	// Assumes 'gamma' for 8-bit per component formats, otherwise 'linear'.  This mirrors the DXGI formats which have _SRGB variants.
	ColorSpace_Gamma = 1,	// Texture data can be displayed directly on the display without any conversion (a.k.a. display native format).
	ColorSpace_Linear = 2,	// Same as gamma but has been converted to a linear representation using DXGI's sRGB conversion algorithm.
};

struct Texture_t
{
	void* handle; // See ETextureType definition above
	ETextureType eType;
	EColorSpace eColorSpace;
};

// Handle to a shared texture (HANDLE on Windows obtained using OpenSharedResource).
typedef uint64_t SharedTextureHandle_t;
#define INVALID_SHARED_TEXTURE_HANDLE	((vr::SharedTextureHandle_t)0)

enum ETrackingResult
{
	TrackingResult_Uninitialized			= 1,

	TrackingResult_Calibrating_InProgress	= 100,
	TrackingResult_Calibrating_OutOfRange	= 101,

	TrackingResult_Running_OK				= 200,
	TrackingResult_Running_OutOfRange		= 201,

	TrackingResult_Fallback_RotationOnly	= 300,
};

typedef uint32_t DriverId_t;
static const uint32_t k_nDriverNone = 0xFFFFFFFF;

static const uint32_t k_unMaxDriverDebugResponseSize = 32768;

/** Used to pass device IDs to API calls */
typedef uint32_t TrackedDeviceIndex_t;
static const uint32_t k_unTrackedDeviceIndex_Hmd = 0;
static const uint32_t k_unMaxTrackedDeviceCount = 64;
static const uint32_t k_unTrackedDeviceIndexOther = 0xFFFFFFFE;
static const uint32_t k_unTrackedDeviceIndexInvalid = 0xFFFFFFFF;

/** Describes what kind of object is being tracked at a given ID */
enum ETrackedDeviceClass
{
	TrackedDeviceClass_Invalid = 0,				// the ID was not valid.
	TrackedDeviceClass_HMD = 1,					// Head-Mounted Displays
	TrackedDeviceClass_Controller = 2,			// Tracked controllers
	TrackedDeviceClass_GenericTracker = 3,		// Generic trackers, similar to controllers
	TrackedDeviceClass_TrackingReference = 4,	// Camera and base stations that serve as tracking reference points
	TrackedDeviceClass_DisplayRedirect = 5,		// Accessories that aren't necessarily tracked themselves, but may redirect video output from other tracked devices

	TrackedDeviceClass_Max
};


/** Describes what specific role associated with a tracked device */
enum ETrackedControllerRole
{
	TrackedControllerRole_Invalid = 0,					// Invalid value for controller type
	TrackedControllerRole_LeftHand = 1,					// Tracked device associated with the left hand
	TrackedControllerRole_RightHand = 2,				// Tracked device associated with the right hand
	TrackedControllerRole_OptOut = 3,					// Tracked device is opting out of left/right hand selection
	TrackedControllerRole_Treadmill = 4,				// Tracked device is a treadmill or other locomotion device
	TrackedControllerRole_Stylus = 5,					// Tracked device is a stylus
	TrackedControllerRole_Max = 5
};


/** Returns true if the tracked controller role is allowed to be a hand */
inline bool IsRoleAllowedAsHand( ETrackedControllerRole eRole )
{
	switch ( eRole )
	{
	case TrackedControllerRole_Invalid:
	case TrackedControllerRole_LeftHand:
	case TrackedControllerRole_RightHand:
		return true;
	default:
		return false;
	}
}


/** describes a single pose for a tracked object */
struct TrackedDevicePose_t
{
	HmdMatrix34_t mDeviceToAbsoluteTracking;
	HmdVector3_t vVelocity;				// velocity in tracker space in m/s
	HmdVector3_t vAngularVelocity;		// angular velocity in radians/s (?)
	ETrackingResult eTrackingResult;
	bool bPoseIsValid;

	// This indicates that there is a device connected for this spot in the pose array.
	// It could go from true to false if the user unplugs the device.
	bool bDeviceIsConnected;
};
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

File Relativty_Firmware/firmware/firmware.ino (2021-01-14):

// Copyright (C) 2020  Max Coutte, Gabriel Combe
// Copyright (C) 2020  Relativty.com
//
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
#include "I2Cdev.h"

#include "MPU6050_6Axis_MotionApps_V6_12.h"
#include "Wire.h"

MPU6050 mpu;

#include "HID.h"
#if !defined(_USING_HID)
#error "Using legacy HID core (non pluggable)"
#endif

static const uint8_t _hidReportDescriptor[] PROGMEM = {
 0x06, 0x00, 0xff,         // USAGE_PAGE (vendor defined)
    0x09, 0x00,         // USAGE (Undefined)
    0xa1, 0x01,         // COLLECTION (Application)
    0x15, 0x00,         //   LOGICAL_MINIMUM (0)
    0x26, 0xff, 0x00,   //   LOGICAL_MAXIMUM (255)
    0x85, 0x01,         //   REPORT_ID (1)
    0x75, 0x08,         //   REPORT_SIZE (8)
    
    0x95, 0x3f,         //   REPORT_COUNT (63)
    
    0x09, 0x00,         //   USAGE (Undefined)
    0x81, 0x02,         //   INPUT (Data,Var,Abs) - to the host
    0xc0           
};

#define INTERRUPT_PIN 2

// MPU control/status vars
bool dmpReady = false;
uint8_t mpuIntStatus;
uint8_t devStatus;
uint16_t packetSize;
uint16_t fifoCount;
uint8_t fifoBuffer[63];

Quaternion q;
VectorInt16 aa;
VectorInt16 gy;
VectorInt16 aaReal;
VectorInt16 aaWorld;
VectorFloat gravity;
float euler[3];
float ypr[3];

volatile bool mpuInterrupt = false;
void dmpDataReady() {
  mpuInterrupt = true;
}

void setup() {
  static HIDSubDescriptor node (_hidReportDescriptor, sizeof(_hidReportDescriptor));
  HID().AppendDescriptor(&node);
  
  Wire.begin();
  Wire.setClock(400000);

  delay(1000);

  mpu.initialize();
  pinMode(INTERRUPT_PIN, INPUT);
  mpu.testConnection();
  devStatus = mpu.dmpInitialize();
  
  mpu.setXGyroOffset(51);
  mpu.setYGyroOffset(8);
  mpu.setZGyroOffset(21);
  mpu.setXAccelOffset(1150);
  mpu.setYAccelOffset(-50);
  mpu.setZAccelOffset(1060);
  
  if (devStatus == 0) {
    mpu.CalibrateAccel(6);
    mpu.CalibrateGyro(6);
    mpu.setDMPEnabled(true);
    
    digitalPinToInterrupt(INTERRUPT_PIN);
    attachInterrupt(digitalPinToInterrupt(INTERRUPT_PIN), dmpDataReady, RISING);
    mpuIntStatus = mpu.getIntStatus();
    dmpReady = true;
    packetSize = mpu.dmpGetFIFOPacketSize();
  } else {
    //ERROR
  }
}

void loop() {
  if (!dmpReady) return;
  
  if (mpu.dmpGetCurrentFIFOPacket(fifoBuffer)) {
    HID().SendReport(1,fifoBuffer,63);
  }
}

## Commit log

2017-12-03 Added 3D models
    [Relativ_headset_structure.SLDPRT, box_Arduino_DUE.SLDPRT, box_Arduino_DUE.stl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]
2017-12-03 spelling mistake
    [Relativ_headset_structure.SLDPRT, box_Arduino_DUE.SLDPRT, box_lens_1.SLDPRT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]
2017-12-04 Change wrong dimensions
    [box_lens_1.SLDPRT, box_lens_1.STL]
2017-12-09 added strap holder
    [Relativ_headset_structure.SLDPRT]
2017-12-09 added box_screen_adaptor
    [box_screen_adaptor.SLDPRT, box_screen_adaptor.STL]
2017-12-27 added box_screen_spherecal
    Optional astetics update
    [box_screen_spherecal.SLDPRT]
2018-01-02 Added basics for Arduino Due
2018-01-04 Added serial print for non-native USB controller
2018-01-23 📝 Fixed typo
2018-02-08 Fix case sensitivity typo. A user was confused by this point. We are not making a static call to the function start(), but invoking it on the already existing instance of the Relativ class, named 're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
2018-02-10 Include more detailed instructions for using non-DUE Arduino boards. Improve comment clarity. Fix text alignment
2018-06-15 wip: [Feature Request] inertial tracking using the onboard imu #21 (#23)
    * wip: adding inertial tracking algorithm from LaValle text
    * wip: added drift correction logic for test
    * wip: added drift correction logic for test
2019-04-03 The yxxy distro (#38)
    * Update README.md
    * Added own 3D-Models for improved version of the headset
    Added notes.txt
    Added Schematic of the project
    * Update README.md
    * Update README.md
    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
    [Part_1_Eyepiece.stl, Part_2a.stl, Part_2b.stl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]
2019-04-14 Changes Readme, and added Vang1 3D models (#39)
    * Vang1 | 3D models
    Added the 3D models of Vang1, so people can choose between the models from Vang1, and TheYXXY.
    * Changed folder name
    Changed the Folder name "3D models" to "TheYXXY 3D models"
    * Changed reamde
    Added some changes for Vang1's 3D models.
    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
    [Part010_-_Lens_Adjuster_LEFT.stl, Part011_-_Lens_mount.stl, Part012_-_Lens_Adjuster_button.stl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]
2019-04-22 Added STM32 code, and fixes in Readme.MD (#43)
    * added STM32 code
    Added STM32 code
    Moved some files to different folders, to make the GitHub more userfriendly.
    * Removed a file
    Removed a file, becuase the info has been added to the main README.md
    * Fixed link
    Fixed the link for the face foam.
    * Fixed typo
    Fixed a typo of the Biconvex lenses
    * Fixed typo's
    Fixed a few more typo's in the Readme.MD
    * Create PULL_REQUEST_TEMPLATE.md
    * Added info Vang1 design
    Added the amount of screws needed to make the Vang1 VR headset.
    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
    [Part010_-_Lens_Adjuster_LEFT.stl, Part011_-_Lens_mount.stl, Part012_-_Lens_Adjuster_button.stl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]
2019-05-24 Added electronic 3D models
    Added the 3D models of the electronics, made by BioToa7 / Assemdox
    [5.5 in lcd.stl, Screen Driver Board.stl, driver board box.stl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]
2019-05-27 Added hardware 3D models
    Added the hardware 3D models, made by Bio Toa7 / Assemdox
    [5.5 in lcd.stl, Screen Driver Board.stl, driver board box.stl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]
2019-06-24 Moving 3D models to thingiverse
    Due to the amount of new 3D models, and remixes that are made of them, we have decided to move our 3D models to thingiverse, and can all be found here; https://www.thingiverse.com/Relativty/designs t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
    [5.5 in lcd.stl, Part010_-_Lens_Adjuster_LEFT.stl, Part011_-_Lens_mount.stl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]
2020-09-09 new hardware, software and firmware
    Much lower latency, full SteamVR supports, 2K@120FPS Display, and much more.
    [body.stl, eyes_panel.stl, foam_support.stl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]
2020-09-13 idk, still trying to fix hid linking errors
    [openvr_driver.h]
2020-09-13 x86 driver compiled
2020-09-13 missing dlls for driver, by @7ep3s#2748
2020-09-13 pid vid are now set by the config
2020-09-13 now logs device vid pid on fail
2020-09-14 new standalone extended display component
    hmd device is not move to using it yet
2020-09-14 hmd device moved to using standalone display component
2020-09-14 hmd render model
    [generic_hmd.obj]
2020-09-14 driver log, had to be a static lib bc VS is bs
2020-09-15 Add Lens specifications so correct lenses can be procured.
2020-09-15 moved to hobovr styled base device class inheritance for openvr integration
2020-09-20 uploaded wrong firmware previously
    [MP9250-HID.ino]
2020-09-20 changed default.vrsettings pid/vid and resolution values to match original defaults
2020-09-23 allot of changes
    * few config sections renamed
    * added ipd setting
    * hmd imu type string setting changed to hmd imu dmp packets bool
    * when hid comm is in quat mode, packet and pose quats are mapped 1 to 1
    * minor pose update thread change
    * driver now logs its "version"
2020-11-17 Note on mpu9250
    Reminder to set hmdIMUdmpPackets to false in the driver for mpu9250 usage.
    Courtesy of @okawo80085
2023-05-21 readme update - wiring and software stuff
2023-05-23 more screenshots + pid vid setup
2023-05-23 screenshots + pid vid setup guide

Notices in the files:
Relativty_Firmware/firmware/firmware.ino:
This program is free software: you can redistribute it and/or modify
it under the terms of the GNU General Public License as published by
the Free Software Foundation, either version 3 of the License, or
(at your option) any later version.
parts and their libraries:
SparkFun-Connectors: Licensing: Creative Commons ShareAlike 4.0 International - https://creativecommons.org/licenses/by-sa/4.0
